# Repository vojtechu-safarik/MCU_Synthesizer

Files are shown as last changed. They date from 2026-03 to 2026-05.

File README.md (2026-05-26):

# Polyphonic Synthesizer for Teensy 4.1 

### Abstract
This project is an advanced realization of bachelor's project at Brno Univesity of Technology. 
It creates a digital synthesizer using a microcontroller development board, encompassing code development and a prototype build (including PCBs).
The C++ code has been made in VS Code using PlatformIO and it utilises Teensy Audio Library. 
The scripts that generate wavetables (as a header file) have been made using Python.
Those header files have been further edited in order to lower the amount of anti-aliasing using a MATLAB script. 

[**Video demonstration of the Synthesizer**](https://youtu.be/89R-V2SBuqk)

## Synthesis controls

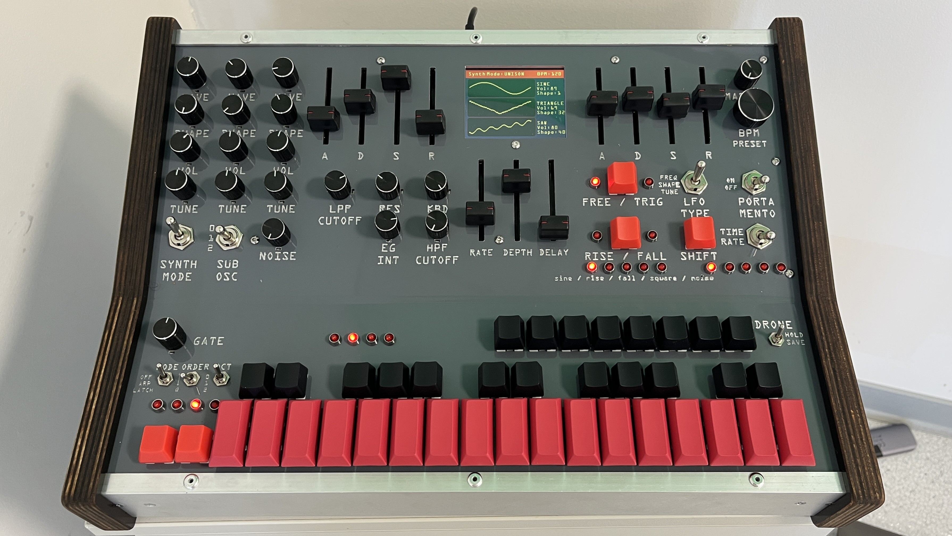
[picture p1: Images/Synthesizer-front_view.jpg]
Synthesizer - front view


### Oscillators
The synthesizer features both Poly and Unison voice allocation modes. Sound generation relies on wavetables categorized into 6 distinct families: Saw, Square (featuring Pulse Width Modulation), Triangle, Sine, Instrument, and Voice. Users can select the waveform type using the `Wave` control and seamlessly interpolate between variations using the `Shape` parameter. In Poly mode, each note gets its own independent audio chain, while Unison mode stacks three parallel oscillators per note for a thicker sound. Additionally, a sub-oscillator can be introduced, transposing the primary frequency one or two octaves down.

### Filters
The signal chain utilizes two main filters. The primary is a 24 dB/oct resonant Low-Pass Filter based on the Huovilainen New Moog mathematical model, which is capable of self-oscillation. This is followed in series by a 12 dB/oct High-Pass Filter based on the State Variable Filter model. The Low-Pass Filter also includes a dedicated Keyboard Tracking feature, allowing the cutoff frequency to scale dynamically with the pitch of the note played.

### Envelopes
Each voice is equipped with two dedicated ADSR (Attack, Decay, Sustain, Release) envelopes, allowing stages up to 3 seconds in length. One envelope shapes the final amplitude of the signal, while the other modulates the Low-Pass Filter's cutoff frequency. The filter envelope also features an `Intensity` control, enabling users to finely scale or invert the depth of the modulation.

### LFO
The Low-Frequency Oscillator can modulate the LPF Cutoff, Oscillator Shape, and Voice Pitch (Detune). It features four operational modes: `Free` (a single global LFO for all voices), `Retrig` (independent LFO per voice), and `Rise` or `Fall` (one-shot linear modulations triggered per note). Available waveforms include Sine, Saw Rise, Saw Fall, Square, and a randomized Noise sample. Users can adjust the modulation `Rate` (0.1–25 Hz), `Depth`, and a fade-in `Delay` of up to 3 seconds.

### Portamento
Available exclusively in Unison mode, Portamento introduces a smooth glide between overlapping notes. Its speed is synchronized to the global BPM and can be operated in two modes: `Time`, where the glide duration is a fixed note division regardless of the pitch distance, and `Rate`, where the glide duration scales with the interval, defined by the time it takes to travel one octave.

### Sequencer
A built-in step sequencer synchronizes to the global BPM and features two main performance modes. `Arp` mode functions as a traditional arpeggiator playing held notes in sequence, whereas `Latch` mode captures pressed keys into a buffer and plays them continuously without requiring the keys to be held. The sequence playback can be customized with order settings (Up, Down, As Played), octave duplications (+1 or +2 octaves), and an adjustable `Gate` parameter defining the note length (1–100%) per step. There's also an option to adjust the each individual step length via secret settings.

### Drone
This alternative ambient mode leverages 10 additional parallel oscillator chains utilizing simplified SVF filters, split into two alternating groups (A and B), alongside independent noise generators. Using the `Save` mode, users can capture the exact parameter settings of currently active voices and store them to one of 8 dedicated buttons. Switching to `Hold` mode allows users to endlessly play back these captured static drones concurrently with the standard synthesis engine.

## List of hardware components

* Teensy 4.1 Development board

* Audio Adaptor Board for Teensy (Rev D)

* 16-Channel Analog/Digital Multiplexer/Demultiplexer, CD74HC4067
  - used for various parameter configuration via potentiometers and toggle switches
  - 3 modules used in total 

  ### Mux 1 Channels:
  | Mux Channel | Parameter name | Connected Component |
  | :--- | :--- | :--- |
  | C0 | **Wave 1** | **Potentiometer** |
  | C1 | **Wave 2** | **Potentiometer** |
  | C2 | **Wave 3** | **Potentiometer** |
  | C3 | **Shape 1** | **Potentiometer** |
  | C4 | **Shape 2** | **Potentiometer** |
  | C5 | **Shape 3** | **Potentiometer** |
  | C6 | **Volume 1** | **Potentiometer** |
  | C7 | **Volume 2** | **Potentiometer** |
  | C8 | **Volume 3** | **Potentiometer** |
  | C9 | **Tune 1** | **Potentiometer** |
  | C10 | **Tune 2** | **Potentiometer** |
  | C11 | **Tune 3** | **Potentiometer** |
  | C12 | **Pink Noise** | **Potentiometer** |
  | C13 | **SynthMode - Poly** | **2-way Toggle Switch** |
  | C14 | **Sub-OSC - OFF** | **3-way Toggle Switch** |
  | C15 | **Sub-OSC - +2 octaves** | **3-way Toggle Switch** |

  ### Mux 2 Channels:
  | Mux Channel | Parameter name | Connected Component |
  | :--- | :--- | :--- |
  | C0 | **LPF Cutoff** | **Potentiometer** |
  | C1 | **LPF Resonance** | **Potentiometer** |
  | C2 | **Keyboard Tracking** | **Potentiometer** |
  | C3 | **Filter Envelope Intensity** | **Potentiometer** |
  | C4 | **HPF Cutoff** | **Potentiometer** |
  | C5 | **Filter Attack** | **Potentiometer** |
  | C6 | **Filter Decay** | **Potentiometer** |
  | C7 | **Filter Sustain** | **Potentiometer** |
  | C8 | **Filter Release** | **Potentiometer** |
  | C9 | **LFO Rate** | **Potentiometer** |
  | C10 | **LFO Depth** | **Potentiometer** |
  | C11 | **LFO Delay** | **Potentiometer** |
  | C12 | **Amplitude Attack** | **Potentiometer** |
  | C13 | **Amplitude Decay** | **Potentiometer** |
  | C14 | **Amplitude Sustain** | **Potentiometer** |
  | C15 | **Amplitude Release** | **Potentiometer** |

  ### Mux 3 Channels:
  | Mux Channel | Parameter name | Connected Component |
  | :--- | :--- | :--- |
  | C0 | **Master Volume** | **Potentiometer** |
  | C1 | **Sequencer Gate** | **Potentiometer** |
  | C2 | **LFO Type - Frequency** | **3-way Toggle Switch** |
  | C3 | **LFO Type - Tune** | **3-way Toggle Switch** |
  | C4 | **Portamento - ON** | **2-way Toggle Switch** |
  | C5 | **Portamento - Mode** | **2-way Toggle Switch** |
  | C6 | **Drone - mode** | **2-way Toggle Switch** |
  | C7 | **Sequencer Mode - OFF** | **3-way Toggle Switch** |
  | C8 | **Sequencer Mode - Latch** | **3-way Toggle Switch** |
  | C9 | **Sequencer Order - Up** | **3-way Toggle Switch** |
  | C10 | **Sequencer Order - Queue** | **3-way Toggle Switch** |
  | C11 | **Sequencer Octaves - 0** | **3-way Toggle Switch** |
  | C12 | **Sequencer Octaves - 2** | **3-way Toggle Switch** |

* 8-bit I/O Expander I2C-Bus, PCF8574T
  - used for LED signals for parameter state identification 
  - 2 modules used in total 

  ### I/O Expander 1 Pinout:
  | I/O Expander Pin | Parameter name |
  | :--- | :--- |
  | P0 | **LFO Mode #1** |
  | P1 | **LFO Mode #2** |
  | P2 | **LFO Mode #3** |
  | P3 | **LFO Mode #4** |
  | P4 | **LFO Wave #1** |
  | P5 | **LFO Wave #2** |
  | P6 | **LFO Wave #3** |
  | P7 | **LFO Wave #4** |

  ### I/O Expander 2 Pinout:
  | I/O Expander Pin | Parameter name |
  | :--- | :--- |
  | P0 | **Sequencer Rate #3** |
  | P1 | **Sequencer Rate #4** |
  | P2 | **LFO Wave #5** |
  | P3 | **Portamento Rate #1** |
  | P4 | **Portamento Rate #2** |
  | P5 | **Portamento Rate #3** |
  | P6 | **Portamento Rate #4** |
  | P7 | **Portamento Rate #5** |

* 3.2" 240x320 TFT display, ILI9341
  - SPI Display used for wavetable state reading

* Potentiometers
  - 20 Rotary B5K (WH148)
  - 11 Slider B10K (60mm)

* Rotary Encoder, KY-040
  - used for BPM configuration
  - button is used for preset selection

* Keyboard switches, MX linear Red
  - set up as a matrix to preserve pins

  Keyboard matrix configuration

* Toggle switches
- 3× KN3 2-way toggle switch
- 2× KN3 3-way toggle switch
- 1× MTS-102 2-way toggle switch
- 3× MTS-103 3-way toggle switch

* Basic electronic components
- Resistors
  - 1× 100 (for Display backlight)
  - 22× 1k (for LEDs)
  - 14× 10k (pull resistors)
- Capacitors
  - 5× Ceramic 100nF (for coupling)
- Diodes
  - 43× 1N4148 (for Keyboard switches)
- LEDs
  - 22× 3mm Red
- Terminal blocks
  - 45× 3-Pin 2.54mm
  - 6× 2-Pin 2.54mm

## Circuit & PCB schematics
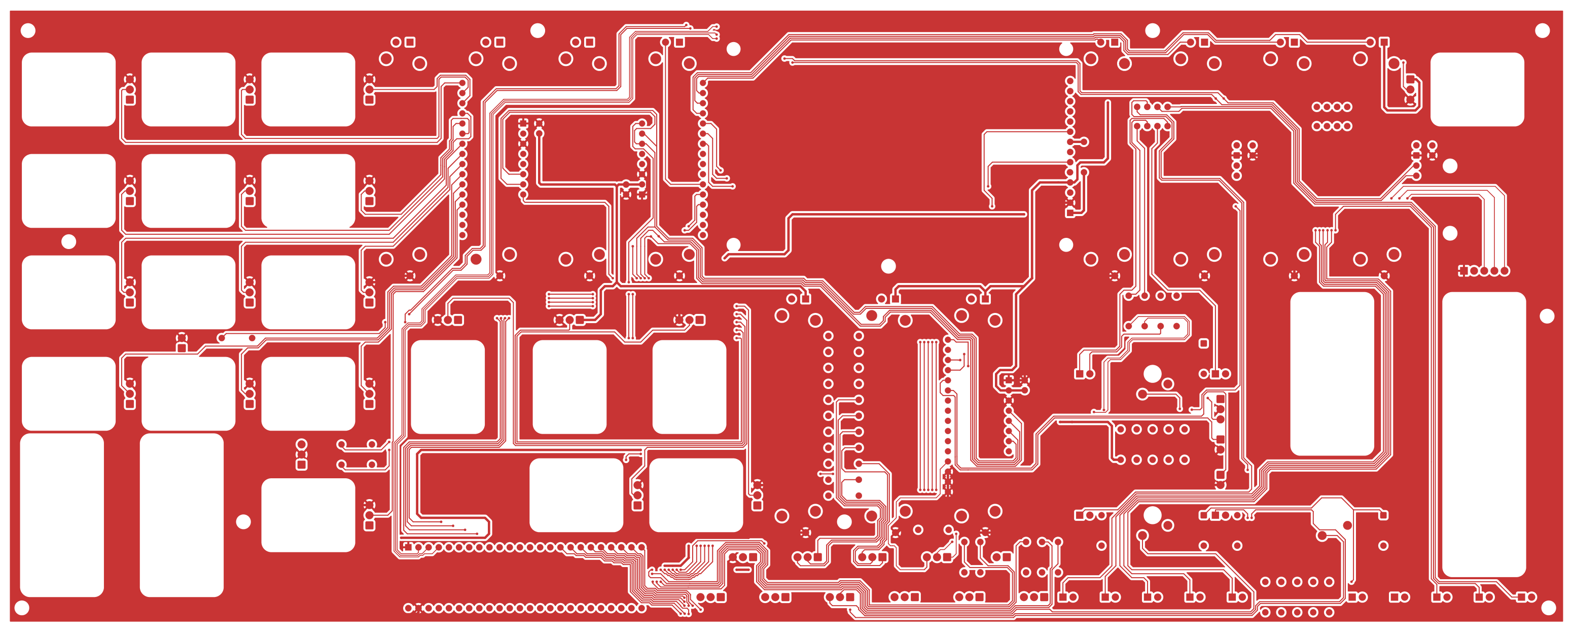
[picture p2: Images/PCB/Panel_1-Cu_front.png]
Main panel PCB - Copper Top

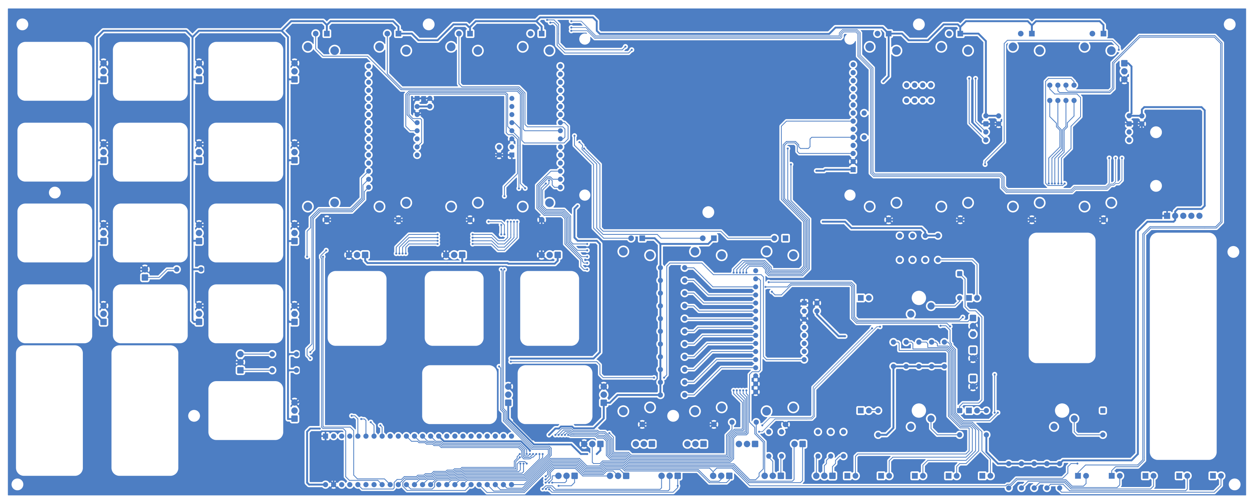
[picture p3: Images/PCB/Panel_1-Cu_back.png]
Main panel PCB - Copper Bottom

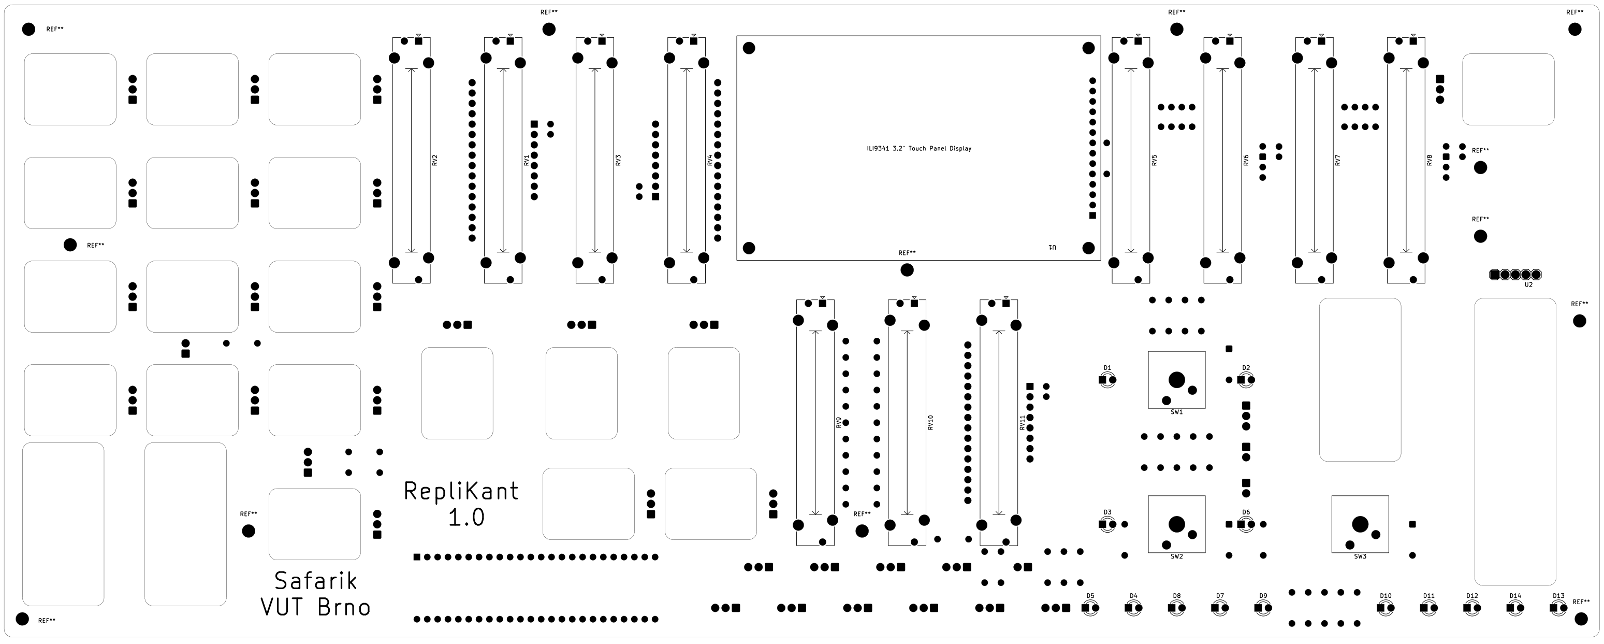
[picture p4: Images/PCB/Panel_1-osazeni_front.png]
Main panel PCB - Parts Top

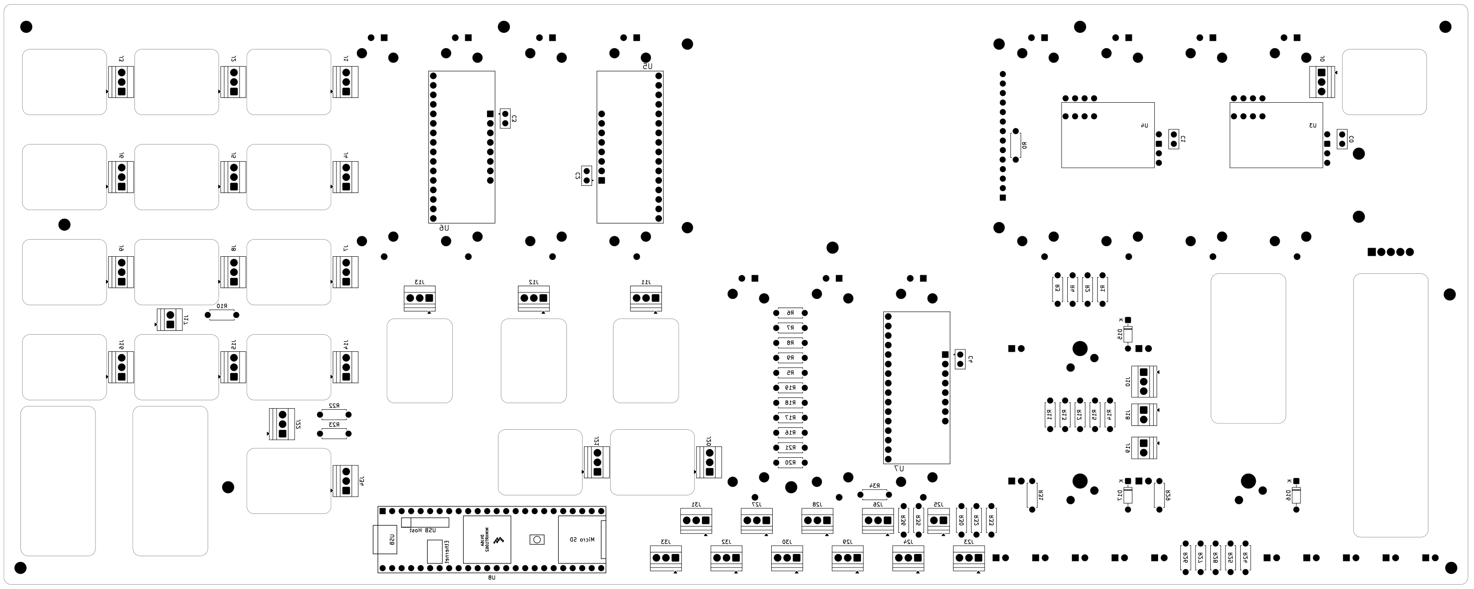
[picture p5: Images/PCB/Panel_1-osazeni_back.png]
Main panel PCB - Parts Bottom

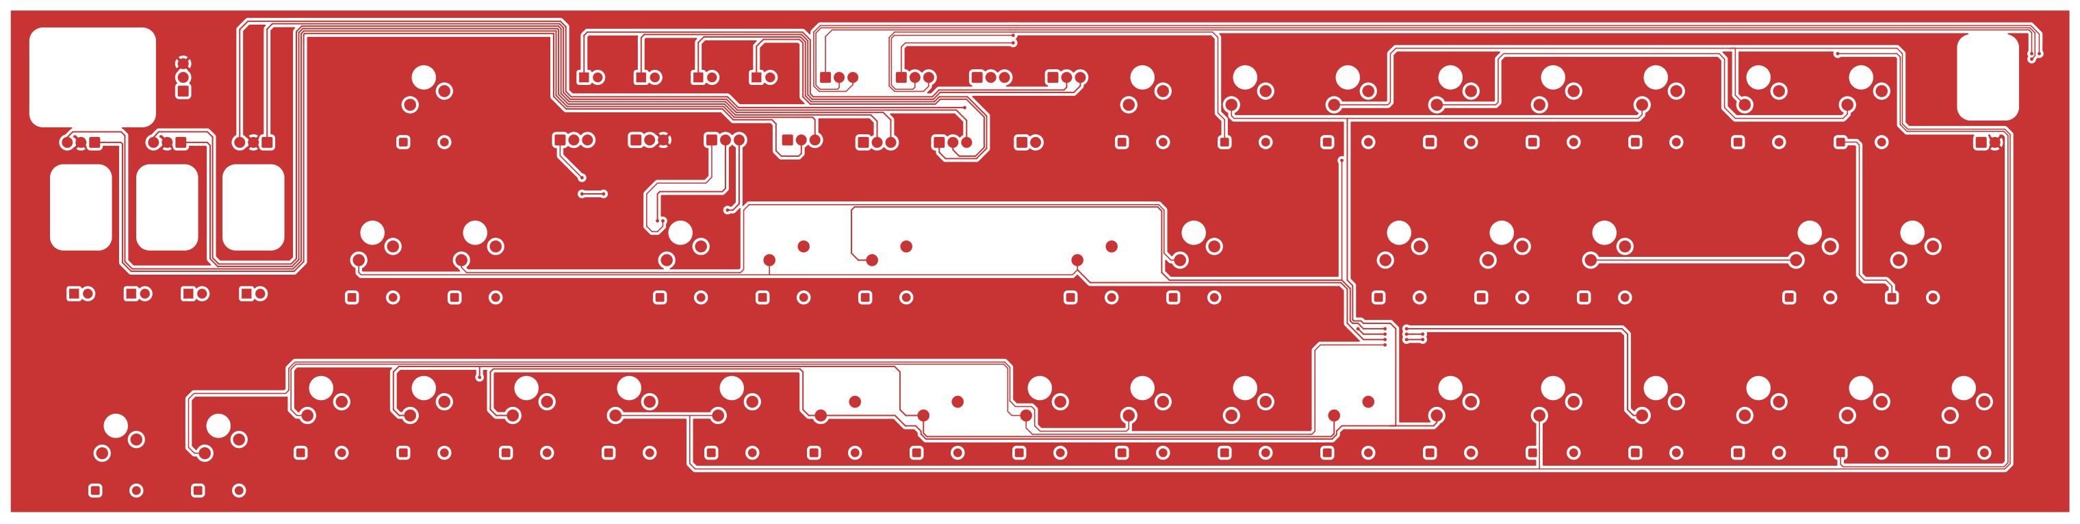
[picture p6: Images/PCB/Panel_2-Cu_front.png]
Keyboard panel PCB - Copper Top

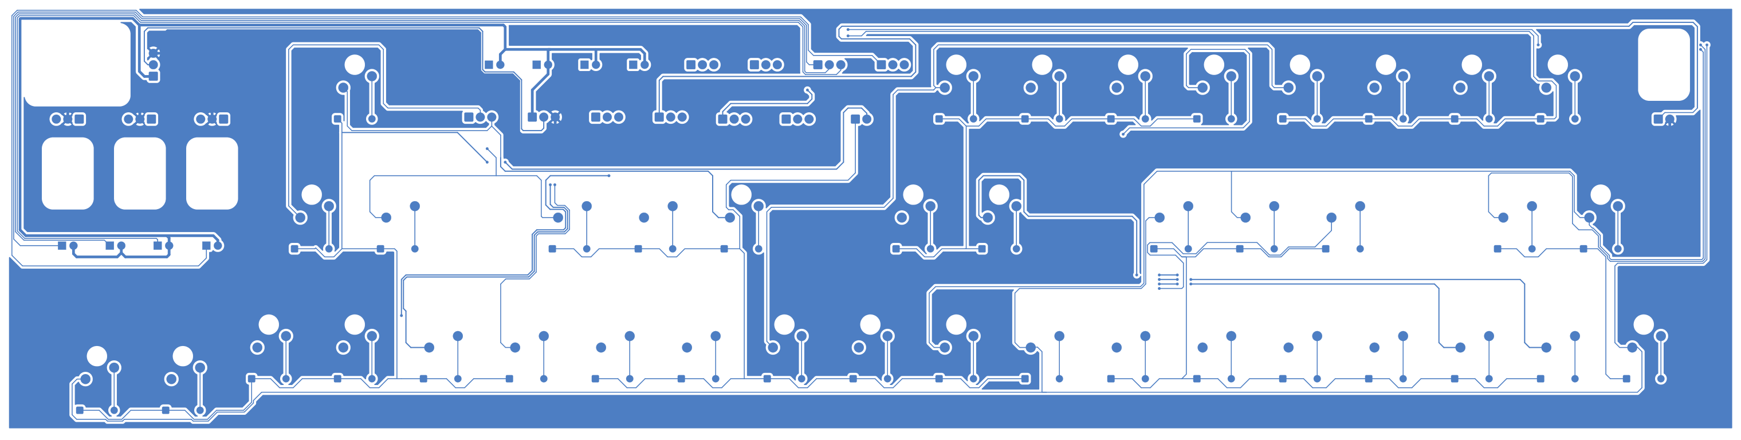
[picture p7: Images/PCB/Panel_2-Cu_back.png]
Keyboard panel PCB - Copper Bottom

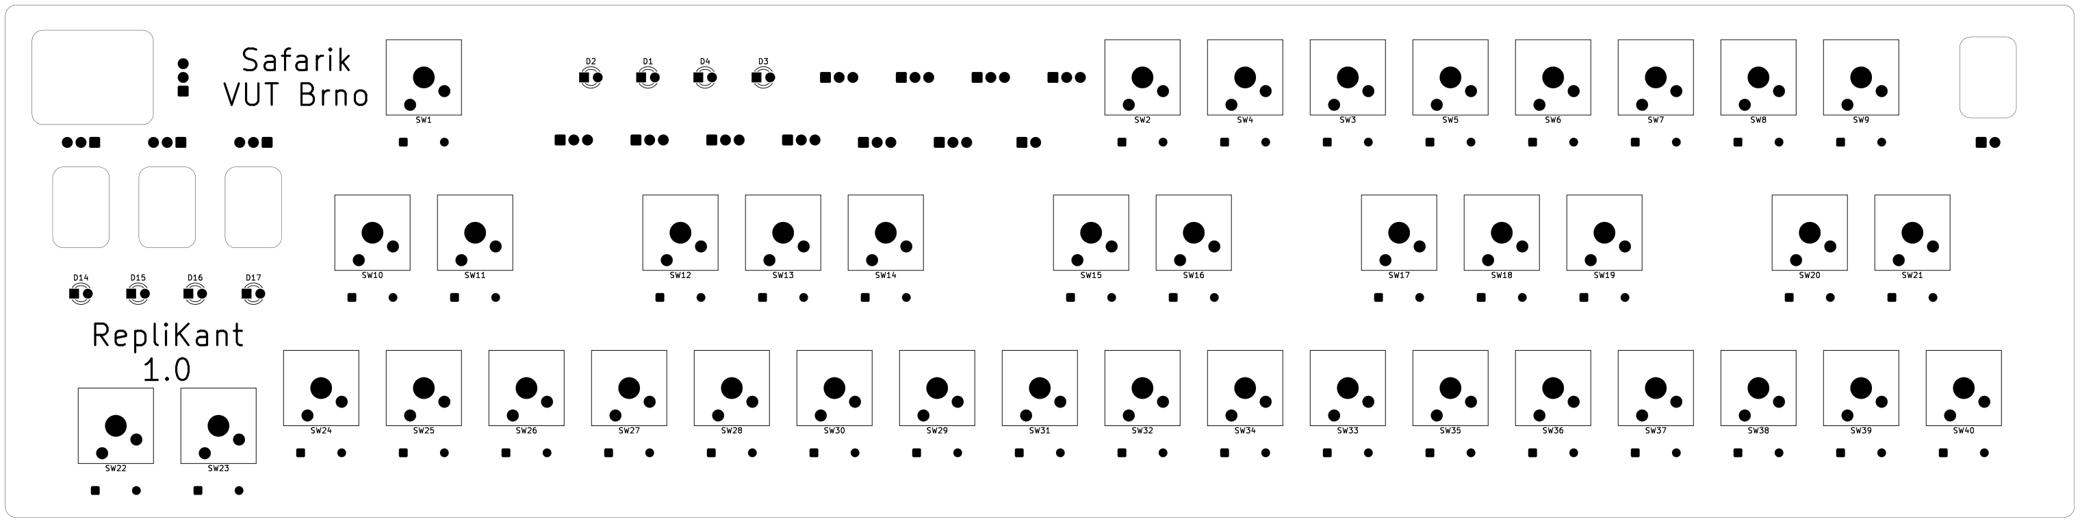
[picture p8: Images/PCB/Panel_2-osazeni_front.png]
Keyboard panel PCB - Parts Top

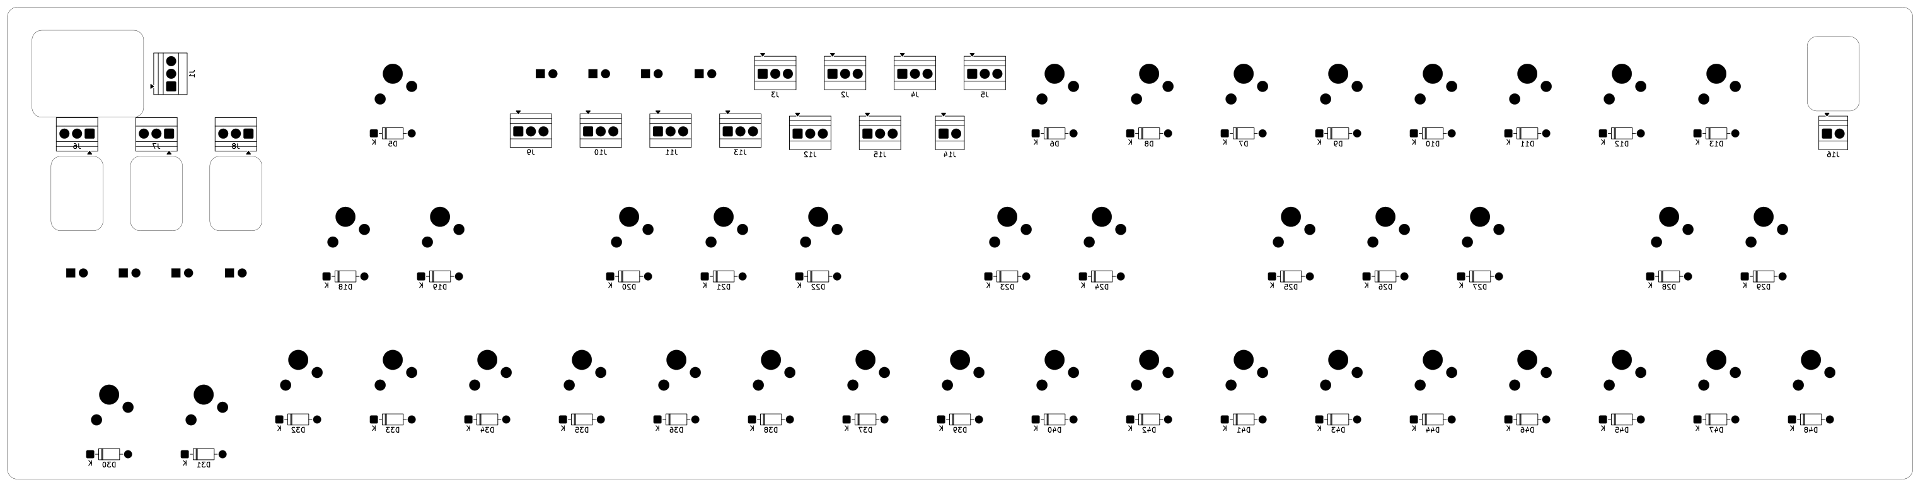
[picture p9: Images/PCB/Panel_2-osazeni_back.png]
Keyboard panel PCB - Parts Bottom


Circuit & PCB schematics have been made in KiCad 9.0 and the project is available [here.](./Design/KiCad)

## Pinout Configuration

| Teensy Pin | Pin name | Connected Components |
| :--- | :--- | :--- |
| 0 | **SW** | **Rotary Encoder** |
| 1 | **DT** | **Rotary Encoder** |
| 2 | **CLK** | **Rotary Encoder** |
| 3 | **S0** | **Mux #1, #2 and #3** |
| 4 | **S1** | **Mux #1, #2 and #3** |
| 5 | **S2** | **Mux #1, #2 and #3** |
| 6 | **S3** | **Mux #1, #2 and #3** |
| 7 | **DIN** | **Audioshield** |
| 8 | **DOUT** | **Audioshield** |
| 9 | **D/C** | **Display** |
| 10 | **CS** | **Display** |
| 11 | **SDI (MOSI)** | **Display** |
| 12 | **SDO (MISO)** | **Display** |
| 13 | **SCK** | **Display** |
| 14 | **Signal #1** | **LED #1 (Sequencer Rate #1)** |
| 15 | **Signal #2** | **LED #2 (Octave #4)** |
| 16 | **Signal #3** | **LED #3 (Octave #3)** |
| 17 | **Signal #4** | **LED #4 (Octave #2)** |
| 18 | **SDA** | **Audioshield** |
| 19 | **SCL** | **Audioshield** |
| 20 | **LRCLK** | **Audioshield** |
| 21 | **BCLK** | **Audioshield** |
| 22 | **Signal #5** | **LED #5 (Octave #1)** |
| 23 | **MCLK** | **Audioshield** |
| 24 | **Row #1** | **Keyboard** |
| 25 | **Row #2** | **Keyboard** |
| 26 | **Row #3** | **Keyboard** |
| 27 | **Row #4** | **Keyboard** |
| 28 | **Row #5** | **Keyboard** |
| 29 | **Row #6** | **Keyboard** |
| 30 | **Row #7** | **Keyboard** |
| 31 | **Row #8** | **Keyboard** |
| 32 | **Row #9** | **Keyboard** |
| 33 | **Column #1** | **Keyboard** |
| 34 | **Column #2** | **Keyboard** |
| 35 | **Column #3** | **Keyboard** |
| 36 | **Column #4** | **Keyboard** |
| 37 | **Column #5** | **Keyboard** |
| 38 | **Signal #6** | **LED #6 (Sequencer Rate #2)** |
| 39 | **Sig (A15)** | **Mux #1** |
| 40 | **Sig (A16)** | **Mux #2** |
| 41 | **Sig (A17)** | **Mux #3** |

### Images

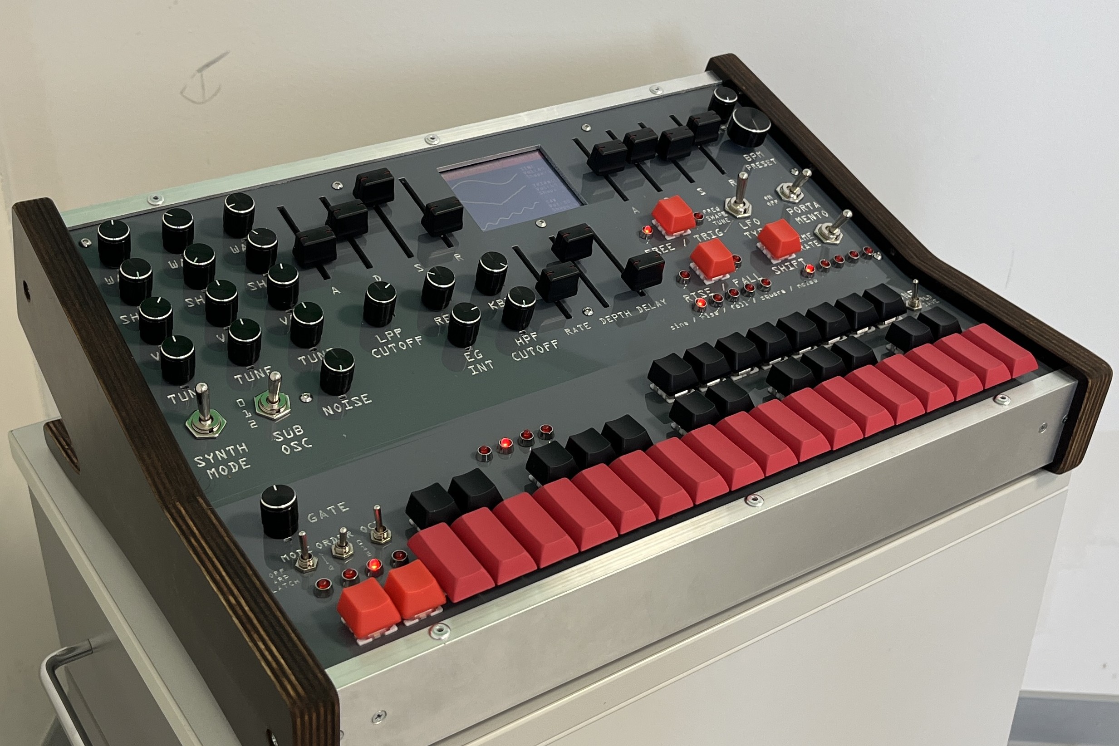
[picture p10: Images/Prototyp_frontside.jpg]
Look from the front

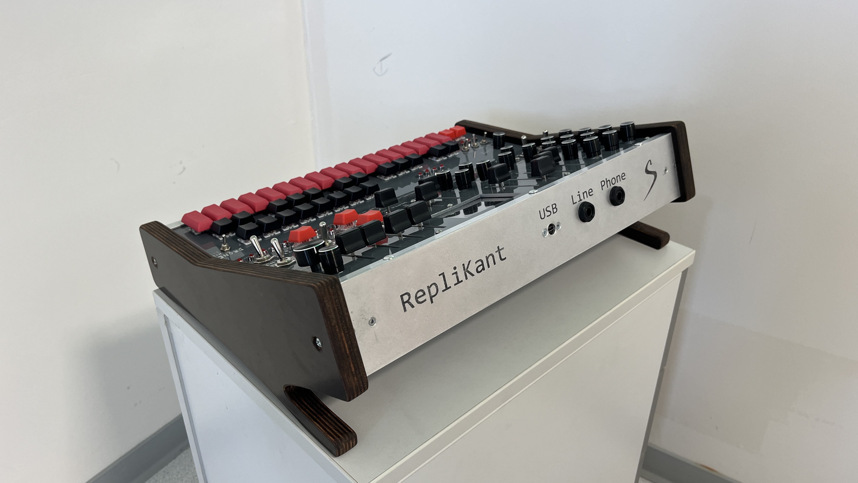
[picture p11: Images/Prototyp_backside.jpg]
Look from the back

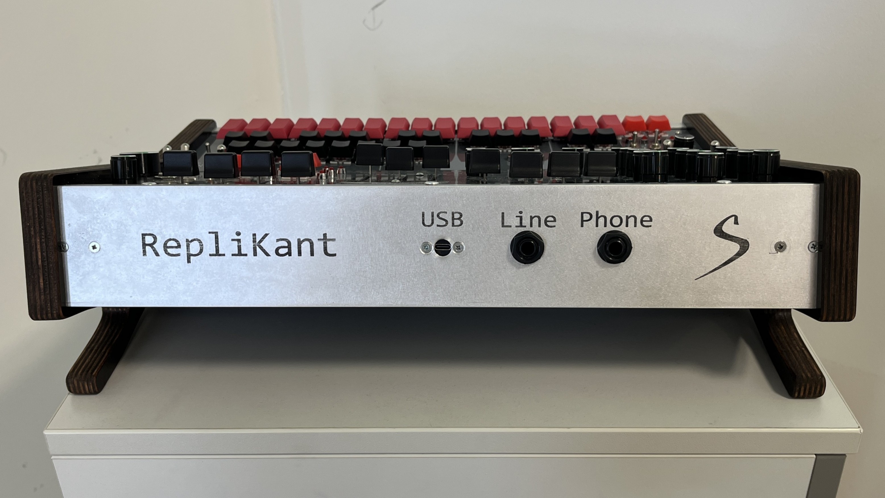
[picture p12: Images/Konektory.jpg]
Connectors


### 3D Model

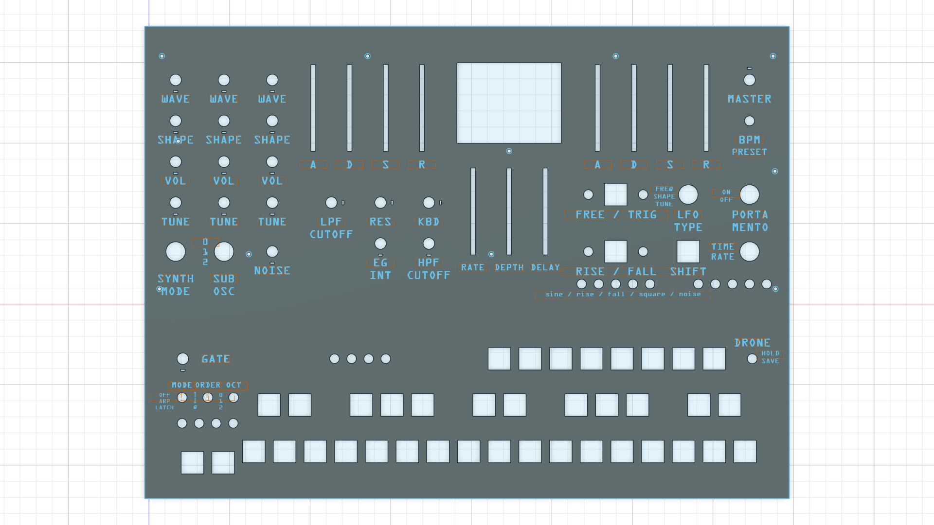
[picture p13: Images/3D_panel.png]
3D Panel


The 3D model has been made for laser engraving of the control panel. 

### Possible improvements

* The Line Out connector doesn't work now, and I don't know why, but I suppose it's not of mechanical nature.
* The GND is pretty noisy as of now, especially when powering via USB.
* Preset function isn't developed yet, but will be once I return to this project later.

## References

* Teensy 4.1 information: [link PJRC.com](https://www.pjrc.com/store/teensy41.html)
* Audio Adaptor Board for Teensy information: [link PJRC.com](https://www.pjrc.com/store/teensy3_audio.html)
* Incredible source of information and amazing YouTube content: [link notesandvolts.com](https://www.notesandvolts.com)
* I hereby acknowledge use of free-license AI tool for coding: [link gemini.google.com](https://gemini.google.com)

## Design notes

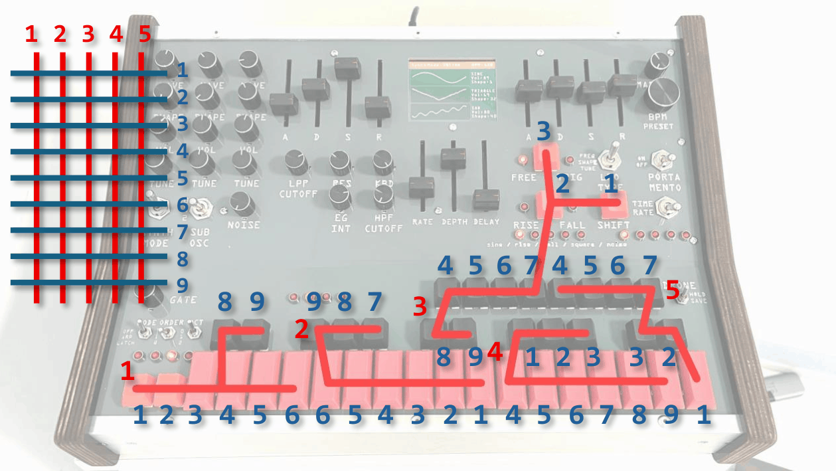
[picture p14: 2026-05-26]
Images/Keyboard_matrix_configuration-1.png

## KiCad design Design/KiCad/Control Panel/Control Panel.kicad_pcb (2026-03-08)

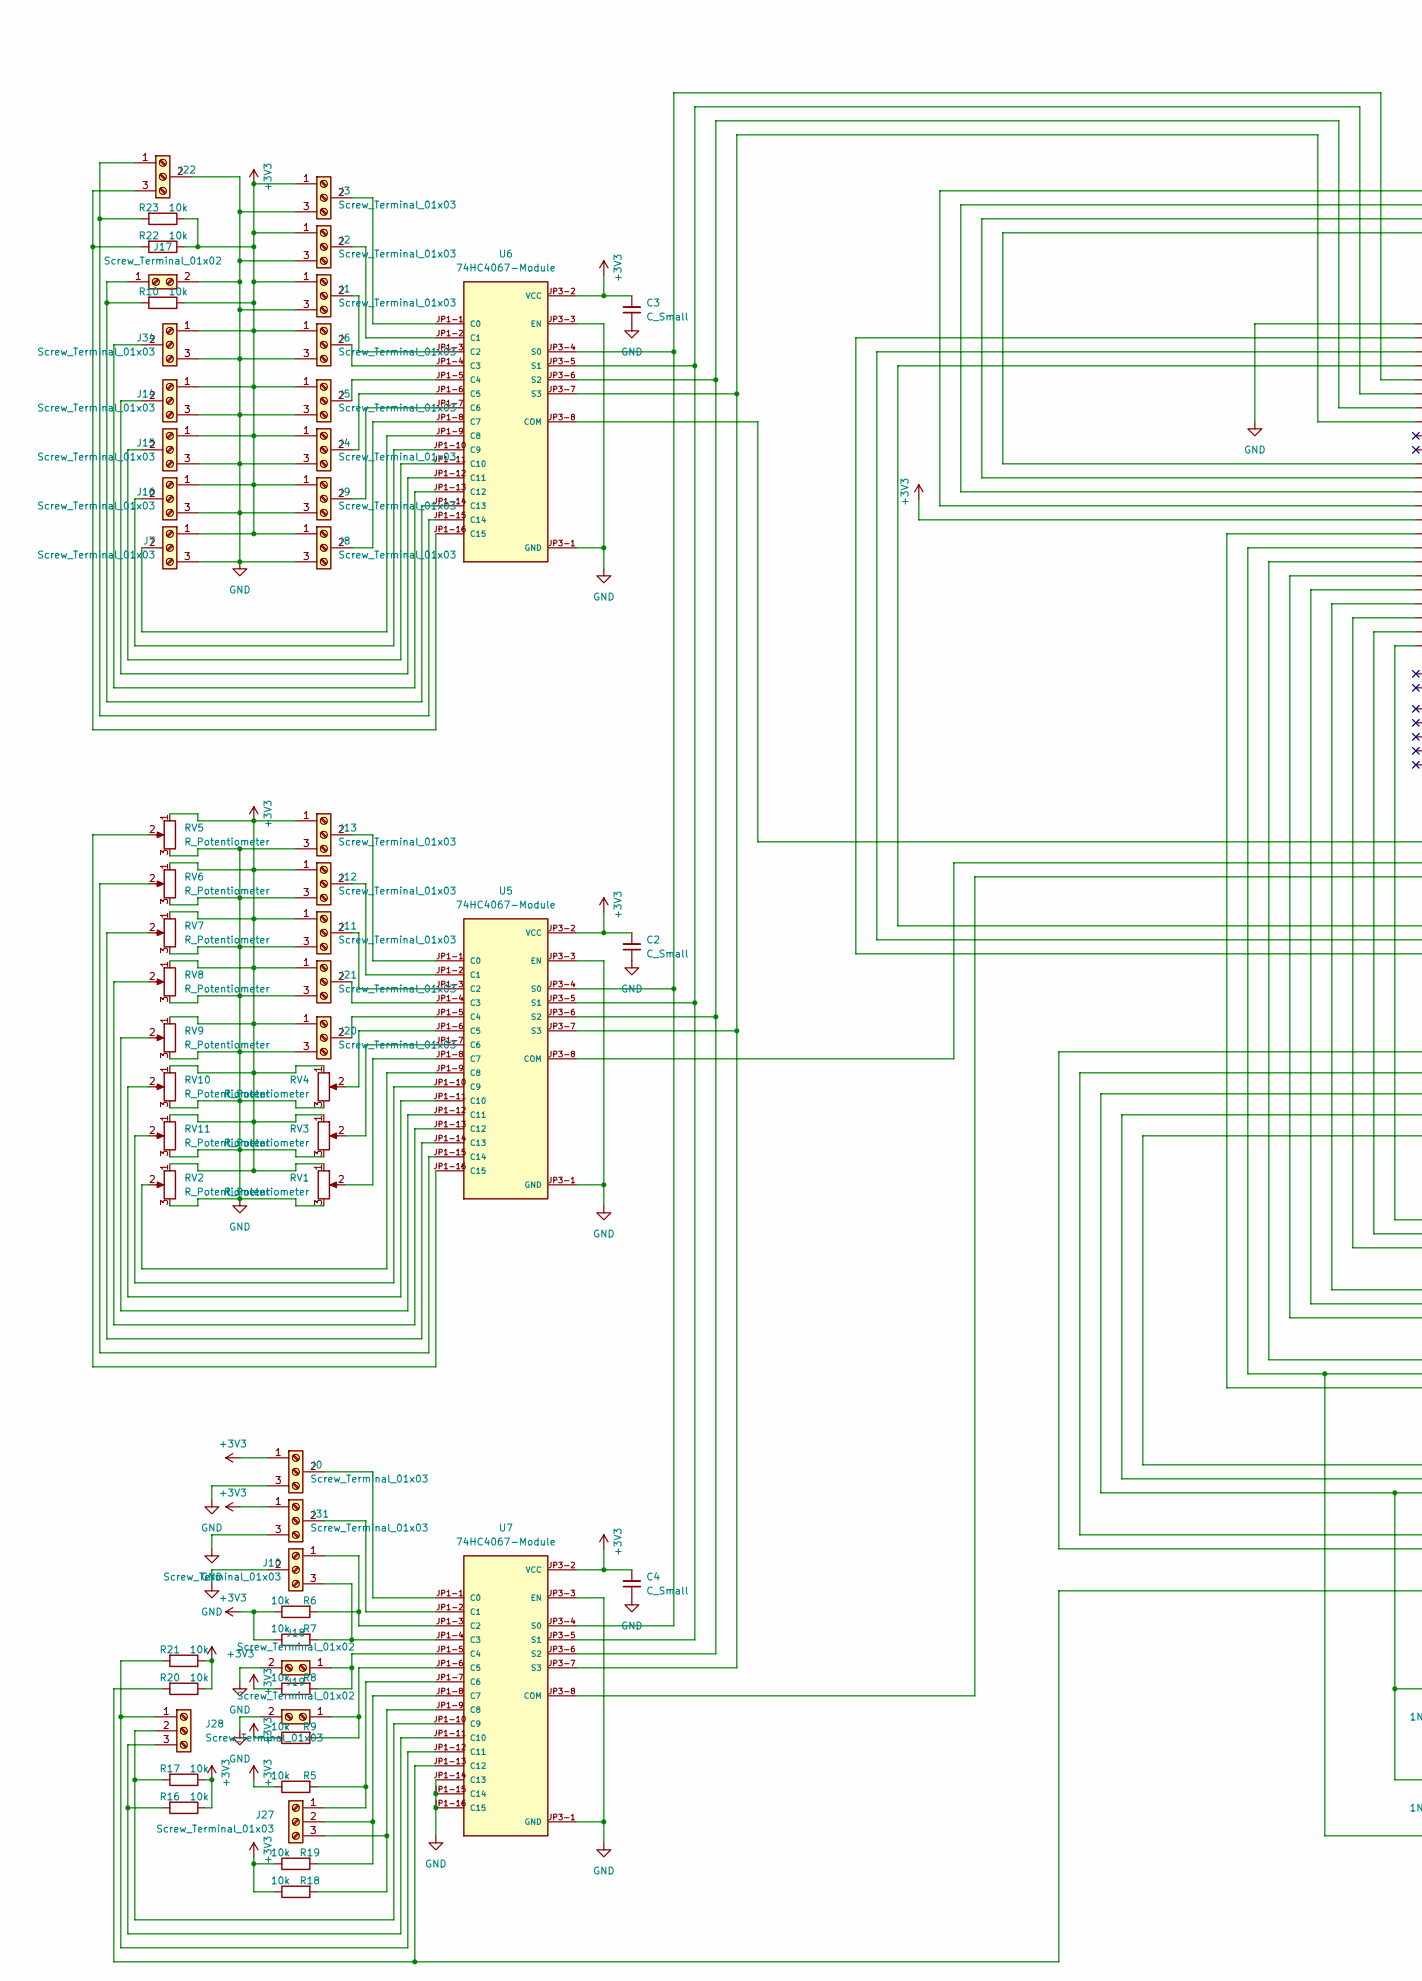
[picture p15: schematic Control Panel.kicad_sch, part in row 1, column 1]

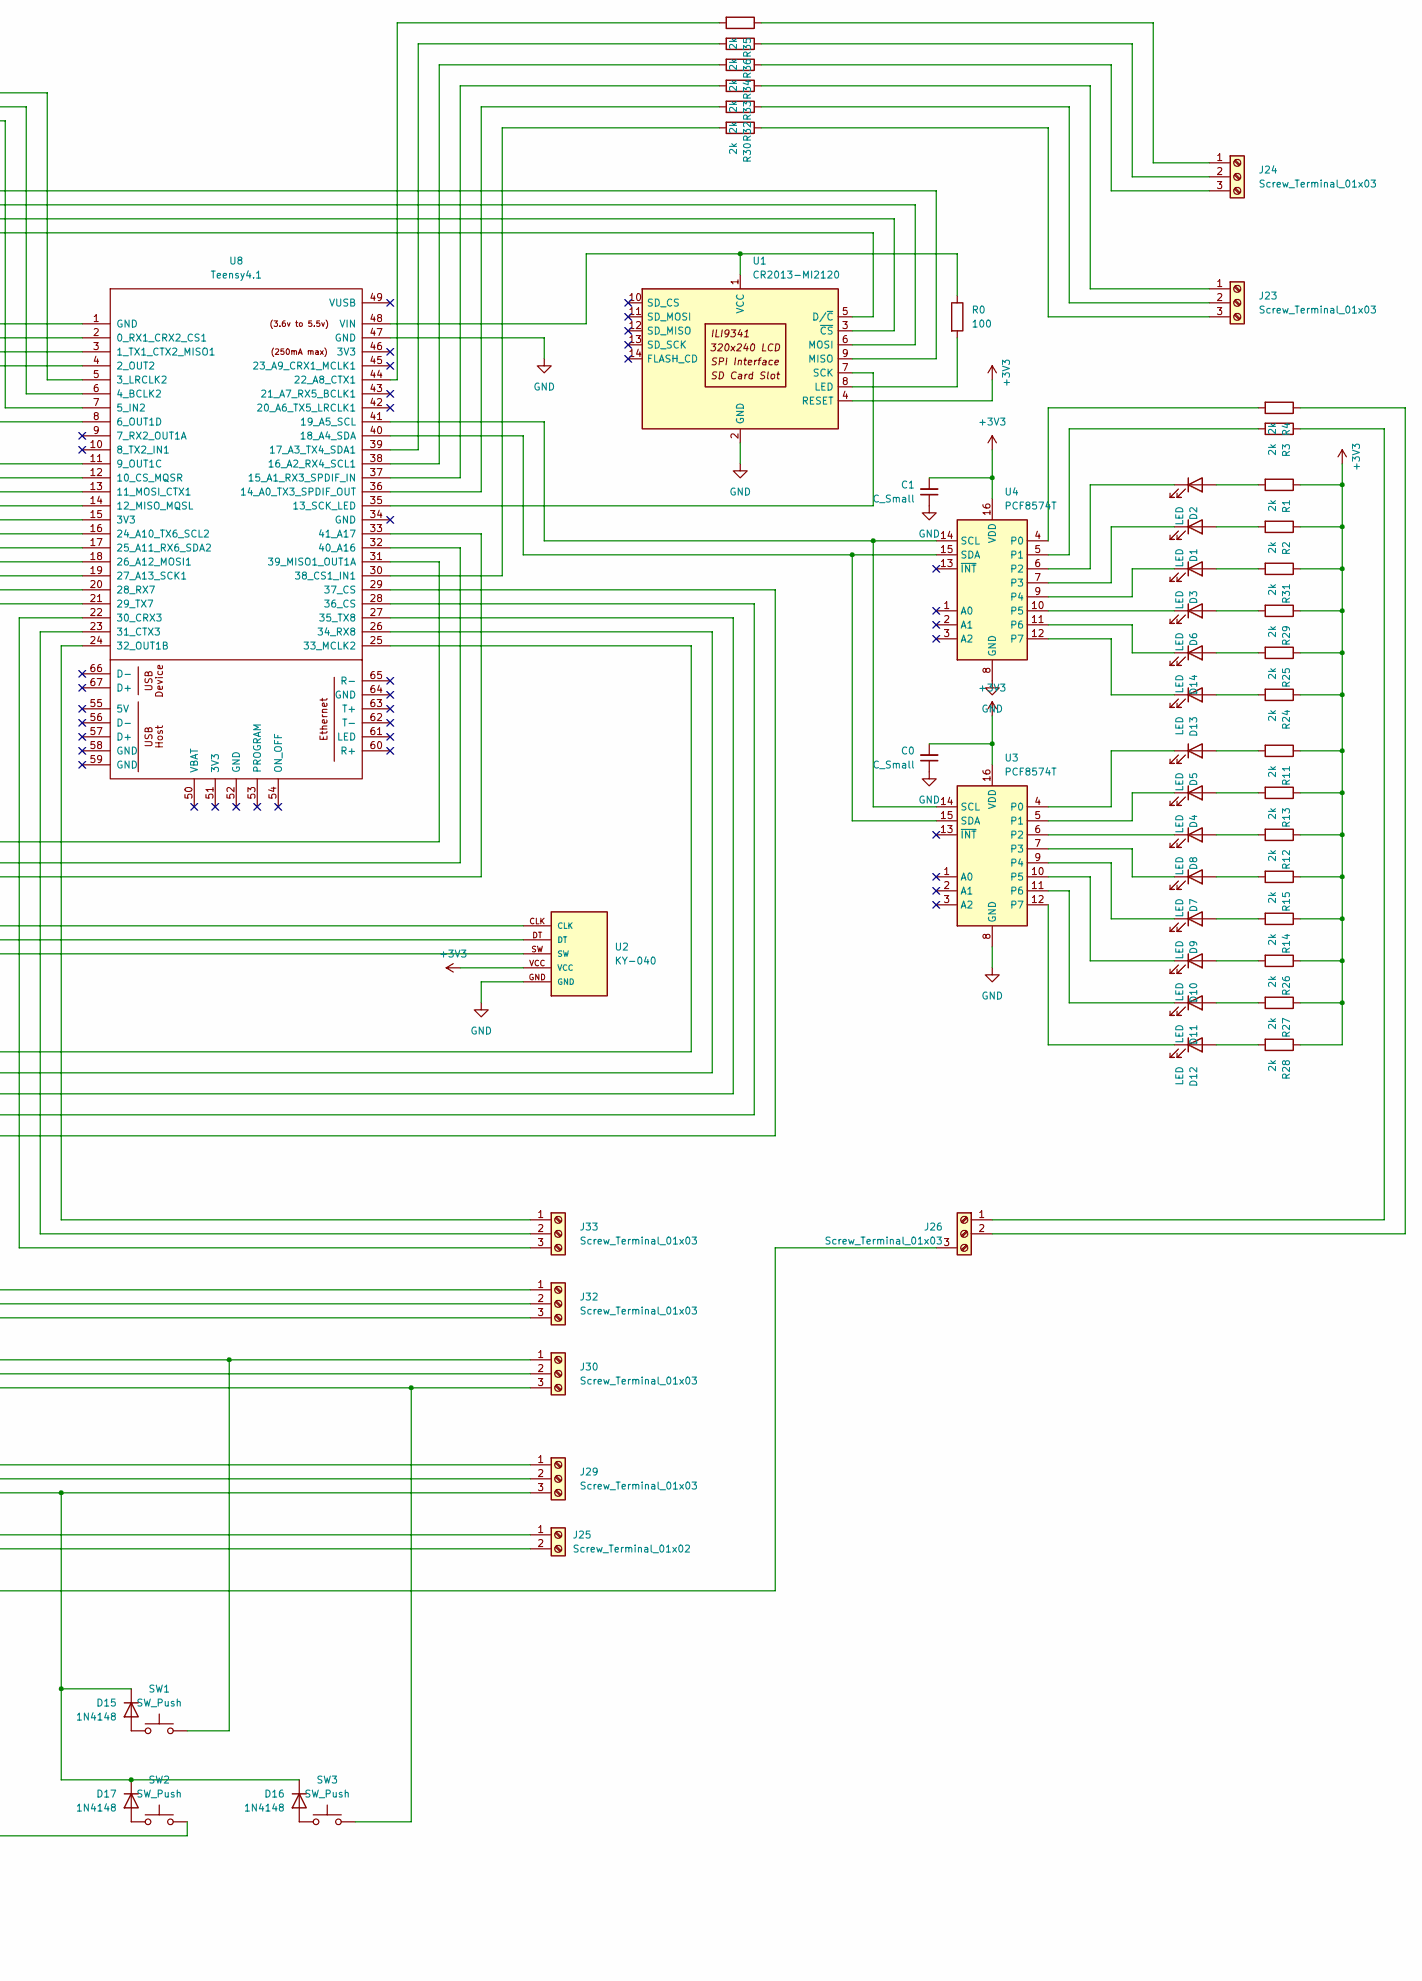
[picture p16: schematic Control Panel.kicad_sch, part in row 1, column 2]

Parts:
C0, C1, C2, C3, C4: C_Small; C_Disc_D5.0mm_W2.5mm_P2.50mm
D1, D2, D3, D4, D5, D6, D7, D8, D9, D10, D11, D12, D13, D14: LED; LED_D3.0mm_Clear
D15, D16, D17: 1N4148; D_DO-35_SOD27_P7.62mm_Horizontal
J0, J1, J2, J3, J4, J5, J6, J7, J8, J9, J10, J11, J12, J13, J14, J15, J16, J20, J21, J22, J23, J24, J26, J27, J28, J29, J30, J31, J32, J33, J34: Screw_Terminal_01x03; TerminalBlock_Xinya_XY308-2.54-3P_1x03_P2.54mm_Horizontal
J17, J18, J19, J25: Screw_Terminal_01x02; TerminalBlock_Xinya_XY308-2.54-2P_1x02_P2.54mm_Horizontal
R0: 100; R_Axial_DIN0207_L6.3mm_D2.5mm_P7.62mm_Horizontal
R1, R2, R3, R4, R11, R12, R13, R14, R15, R24, R25, R26, R27, R28, R29, R30, R31, R32, R33, R34, R35, R36: 2k; R_Axial_DIN0207_L6.3mm_D2.5mm_P7.62mm_Horizontal
R5, R6, R7, R8, R9, R10, R16, R17, R18, R19, R20, R21, R22, R23: 10k; R_Axial_DIN0207_L6.3mm_D2.5mm_P7.62mm_Horizontal
RV1, RV2, RV3, RV4, RV5, RV6, RV7, RV8, RV9, RV10, RV11: R_Potentiometer; Potentiometer_Bourns_PTA4543_Single_Slide
SW1, SW2, SW3: SW_Push; SW_Cherry_MX_1.00u_Plate
U1: CR2013-MI2120; ILI9341_3p2_320x240
U2: KY-040; KY-040-PORT
U3, U4: PCF8574T; PCF8574T_Custom
U5, U6, U7: 74HC4067-Module; MODULE-74HC4067; PARTREV v11
U8: Teensy4.1; Teensy41

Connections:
+3V3: C0.2, C1.2, C2.2, C3.2, C4.2, J0.1, J1.1, J2.1, J3.1, J4.1, J5.1, J6.1, J7.1, J8.1, J9.1, J11.1, J12.1, J13.1, J14.1, J15.1, J16.1, J20.1, J21.1, J31.1, J34.1, R1.1, R2.1, R5.1, R6.1, R7.1, R8.1, R9.1, R10.1, R11.1, R12.1, R13.1, R14.1, R15.1, R16.1, R17.1, R18.1, R19.1, R20.1, R21.1, R22.1, R23.1, R24.1, R25.1, R26.1, R27.1, R28.1, R29.1, R31.1, RV1.1, RV2.1, RV3.1, RV4.1, RV5.1, RV6.1, RV7.1, RV8.1, RV9.1, RV10.1, RV11.1, U1.4 (RESET), U2.VCC, U3.16 (VDD), U4.16 (VDD), U5.JP3-2 (VCC), U6.JP3-2 (VCC), U7.JP3-2 (VCC), U8.15 (3V3)
GND: C0.1, C1.1, C2.1, C3.1, C4.1, J0.3, J1.3, J2.3, J3.3, J4.3, J5.3, J6.3, J7.3, J8.3, J9.3, J10.2, J11.3, J12.3, J13.3, J14.3, J15.3, J16.3, J17.2, J18.2, J19.2, J20.3, J21.3, J22.2, J31.3, J34.3, RV1.3, RV2.3, RV3.3, RV4.3, RV5.3, RV6.3, RV7.3, RV8.3, RV9.3, RV10.3, RV11.3, U1.2 (GND), U2.GND, U3.8 (GND), U4.8 (GND), U5.JP3-1 (GND), U5.JP3-3 (EN), U6.JP3-1 (GND), U6.JP3-3 (EN), U7.JP1-14 (C13), U7.JP1-15 (C14), U7.JP1-16 (C15), U7.JP3-1 (GND), U7.JP3-3 (EN), U8.1 (GND), U8.47 (GND)
unnamed: D1.2 (A), R2.2
unnamed: D1.1 (K), U4.7 (P3)
unnamed: D2.2 (A), R1.2
unnamed: D2.1 (K), U4.6 (P2)
unnamed: D3.2 (A), R31.2
unnamed: D3.1 (K), U4.9 (P4)
unnamed: D4.2 (A), R13.2
unnamed: D4.1 (K), U3.5 (P1)
unnamed: D5.2 (A), R11.2
unnamed: D5.1 (K), U3.4 (P0)
unnamed: D6.2 (A), R29.2
unnamed: D6.1 (K), U4.10 (P5)
unnamed: D7.2 (A), R15.2
unnamed: D7.1 (K), U3.7 (P3)
unnamed: D8.2 (A), R12.2
unnamed: D8.1 (K), U3.6 (P2)
unnamed: D9.2 (A), R14.2
unnamed: D9.1 (K), U3.9 (P4)
unnamed: D10.2 (A), R26.2
unnamed: D10.1 (K), U3.10 (P5)
unnamed: D11.2 (A), R27.2
unnamed: D11.1 (K), U3.11 (P6)
unnamed: D12.2 (A), R28.2
unnamed: D12.1 (K), U3.12 (P7)
unnamed: D13.2 (A), R24.2
unnamed: D13.1 (K), U4.12 (P7)
unnamed: D14.2 (A), R25.2
unnamed: D14.1 (K), U4.11 (P6)
unnamed: D15.2 (A), SW1.2
unnamed: D15.1 (K), D16.1 (K), D17.1 (K), J29.3, U8.27 (35_TX8)
unnamed: D16.2 (A), SW3.2
unnamed: D17.2 (A), SW2.2
unnamed: J0.2, U7.JP1-1 (C0)
unnamed: J1.2, U6.JP1-3 (C2)
unnamed: J2.2, U6.JP1-2 (C1)
unnamed: J3.2, U6.JP1-1 (C0)
unnamed: J4.2, U6.JP1-6 (C5)
unnamed: J5.2, U6.JP1-5 (C4)
unnamed: J6.2, U6.JP1-4 (C3)
unnamed: J7.2, U6.JP1-9 (C8)
unnamed: J8.2, U6.JP1-8 (C7)
unnamed: J9.2, U6.JP1-7 (C6)
unnamed: J10.1, R6.2, U7.JP1-3 (C2)
unnamed: J10.3, R7.2, U7.JP1-4 (C3)
unnamed: J11.2, U5.JP1-3 (C2)
unnamed: J12.2, U5.JP1-2 (C1)
unnamed: J13.2, U5.JP1-1 (C0)
unnamed: J14.2, U6.JP1-12 (C11)
unnamed: J15.2, U6.JP1-11 (C10)
unnamed: J16.2, U6.JP1-10 (C9)
unnamed: J17.1, R10.2, U6.JP1-14 (C13)
unnamed: J18.1, R8.2, U7.JP1-5 (C4)
unnamed: J19.1, R9.2, U7.JP1-6 (C5)
unnamed: J20.2, U5.JP1-5 (C4)
unnamed: J21.2, U5.JP1-4 (C3)
unnamed: J22.1, R23.2, U6.JP1-15 (C14)
unnamed: J22.3, R22.2, U6.JP1-16 (C15)
unnamed: J23.1, R33.1
unnamed: J23.2, R32.1
unnamed: J23.3, R30.1
unnamed: J24.1, R35.1
unnamed: J24.2, R36.1
unnamed: J24.3, R34.1
unnamed: J25.1, U8.26 (34_RX8)
unnamed: J25.2, U8.25 (33_MCLK2)
unnamed: J26.1, R3.1
unnamed: J26.2, R4.1
unnamed: J26.3, R20.2, U7.JP1-13 (C12)
unnamed: J27.1, R5.2, U7.JP1-7 (C6)
unnamed: J27.2, R19.2, U7.JP1-8 (C7)
unnamed: J27.3, R18.2, U7.JP1-9 (C8)
unnamed: J28.1, R21.2, U7.JP1-12 (C11)
unnamed: J28.2, R17.2, U7.JP1-10 (C9)
unnamed: J28.3, R16.2, U7.JP1-11 (C10)
unnamed: J29.1, U8.29 (37_CS)
unnamed: J29.2, U8.28 (36_CS)
unnamed: J30.1, SW1.1, U8.18 (26_A12_MOSI1)
unnamed: J30.2, SW2.1, U8.17 (25_A11_RX6_SDA2)
unnamed: J30.3, SW3.1, U8.16 (24_A10_TX6_SCL2)
unnamed: J31.2, U7.JP1-2 (C1)
unnamed: J32.1, U8.21 (29_TX7)
unnamed: J32.2, U8.20 (28_RX7)
unnamed: J32.3, U8.19 (27_A13_SCK1)
unnamed: J33.1, U8.24 (32_OUT1B)
unnamed: J33.2, U8.23 (31_CTX3)
unnamed: J33.3, U8.22 (30_CRX3)
unnamed: J34.2, U6.JP1-13 (C12)
unnamed: U1.5 (D/~C), U8.11 (9_OUT1C)
unnamed: R0.2, U1.8 (LED)
unnamed: U1.9 (MISO), U8.14 (12_MISO_MQSL)
unnamed: U1.6 (MOSI), U8.13 (11_MOSI_CTX1)
unnamed: U1.7 (SCK), U8.35 (13_SCK_LED)
unnamed: R0.1, U1.1 (VCC), U8.48 (VIN)
unnamed: U1.3 (~CS), U8.12 (10_CS_MQSR)
unnamed: U3.14 (SCL), U4.14 (SCL), U8.41 (19_A5_SCL)
unnamed: U3.15 (SDA), U4.15 (SDA), U8.40 (18_A4_SDA)
unnamed: R4.2, U4.4 (P0)
unnamed: R3.2, U4.5 (P1)
unnamed: RV4.2, U5.JP1-6 (C5)
unnamed: RV3.2, U5.JP1-7 (C6)
unnamed: RV1.2, U5.JP1-8 (C7)
unnamed: RV2.2, U5.JP1-9 (C8)
unnamed: RV11.2, U5.JP1-10 (C9)
unnamed: RV10.2, U5.JP1-11 (C10)
unnamed: RV9.2, U5.JP1-12 (C11)
unnamed: RV8.2, U5.JP1-13 (C12)
unnamed: RV7.2, U5.JP1-14 (C13)
unnamed: RV6.2, U5.JP1-15 (C14)
unnamed: RV5.2, U5.JP1-16 (C15)
unnamed: U5.JP3-8 (COM), U8.32 (40_A16)
unnamed: U5.JP3-4 (S0), U6.JP3-4 (S0), U7.JP3-4 (S0), U8.5 (3_LRCLK2)
unnamed: U5.JP3-5 (S1), U6.JP3-5 (S1), U7.JP3-5 (S1), U8.6 (4_BCLK2)
unnamed: U5.JP3-6 (S2), U6.JP3-6 (S2), U7.JP3-6 (S2), U8.7 (5_IN2)
unnamed: U5.JP3-7 (S3), U6.JP3-7 (S3), U7.JP3-7 (S3), U8.8 (6_OUT1D)
unnamed: U6.JP3-8 (COM), U8.31 (39_MISO1_OUT1A)
unnamed: U7.JP3-8 (COM), U8.33 (41_A17)
unnamed: U2.SW, U8.2 (0_RX1_CRX2_CS1)
unnamed: U2.DT, U8.3 (1_TX1_CTX2_MISO1)
unnamed: U2.CLK, U8.4 (2_OUT2)
unnamed: R32.2, U8.36 (14_A0_TX3_SPDIF_OUT)
unnamed: R33.2, U8.37 (15_A1_RX3_SPDIF_IN)
unnamed: R34.2, U8.38 (16_A2_RX4_SCL1)
unnamed: R36.2, U8.39 (17_A3_TX4_SDA1)
unnamed: R35.2, U8.44 (22_A8_CTX1)
unnamed: R30.2, U8.30 (38_CS1_IN1)

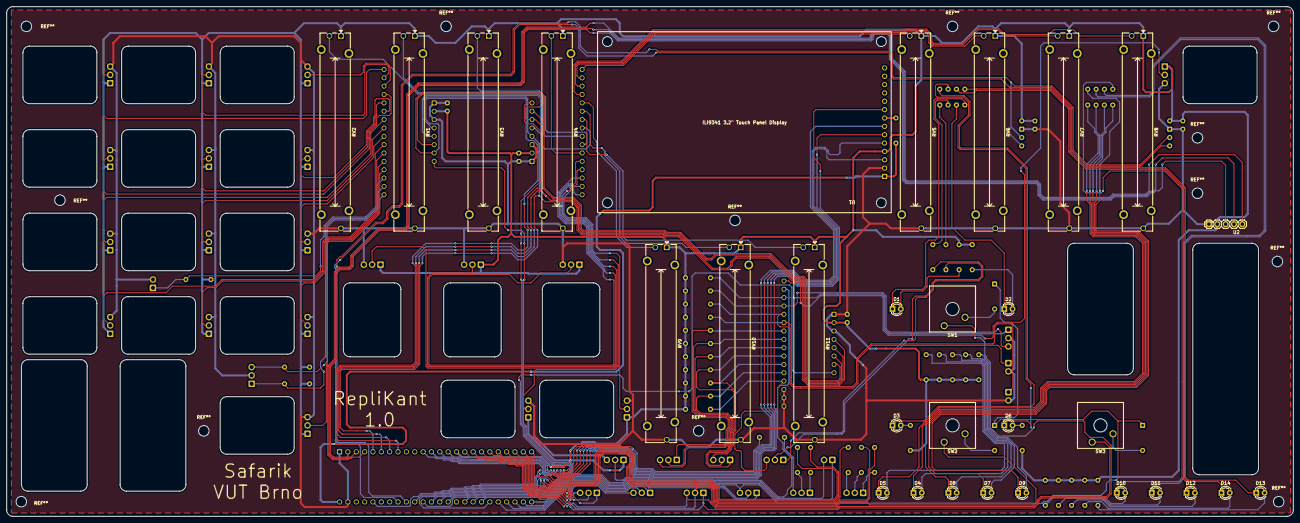
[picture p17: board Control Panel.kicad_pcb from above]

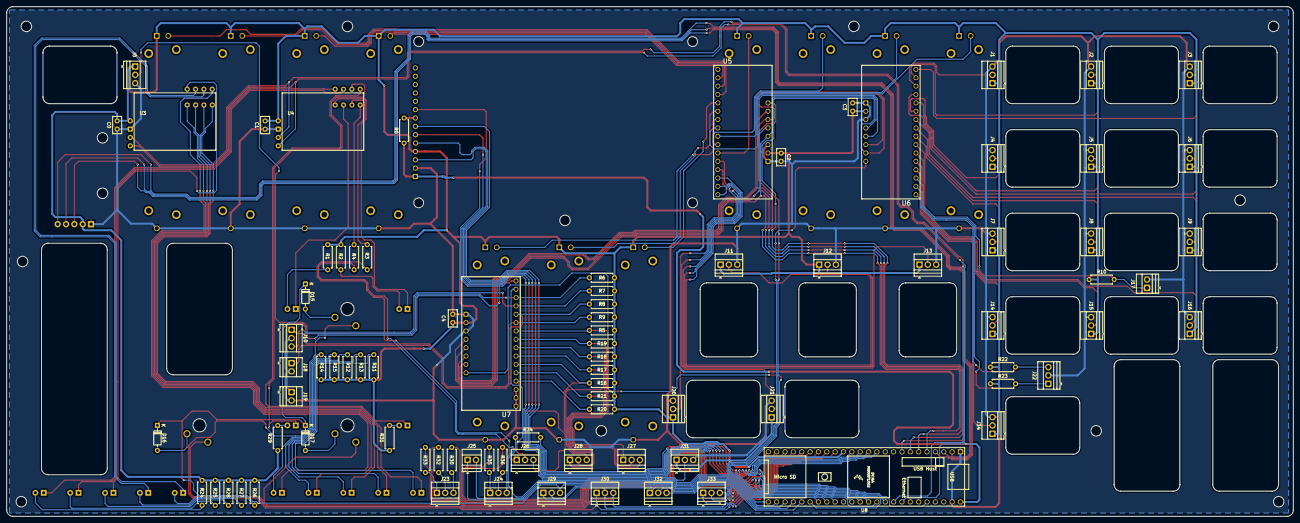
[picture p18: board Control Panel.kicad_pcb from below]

Board: 2 copper layers, 391.3 x 155.0 mm, 116 parts (86 on the bottom side), 127 nets.

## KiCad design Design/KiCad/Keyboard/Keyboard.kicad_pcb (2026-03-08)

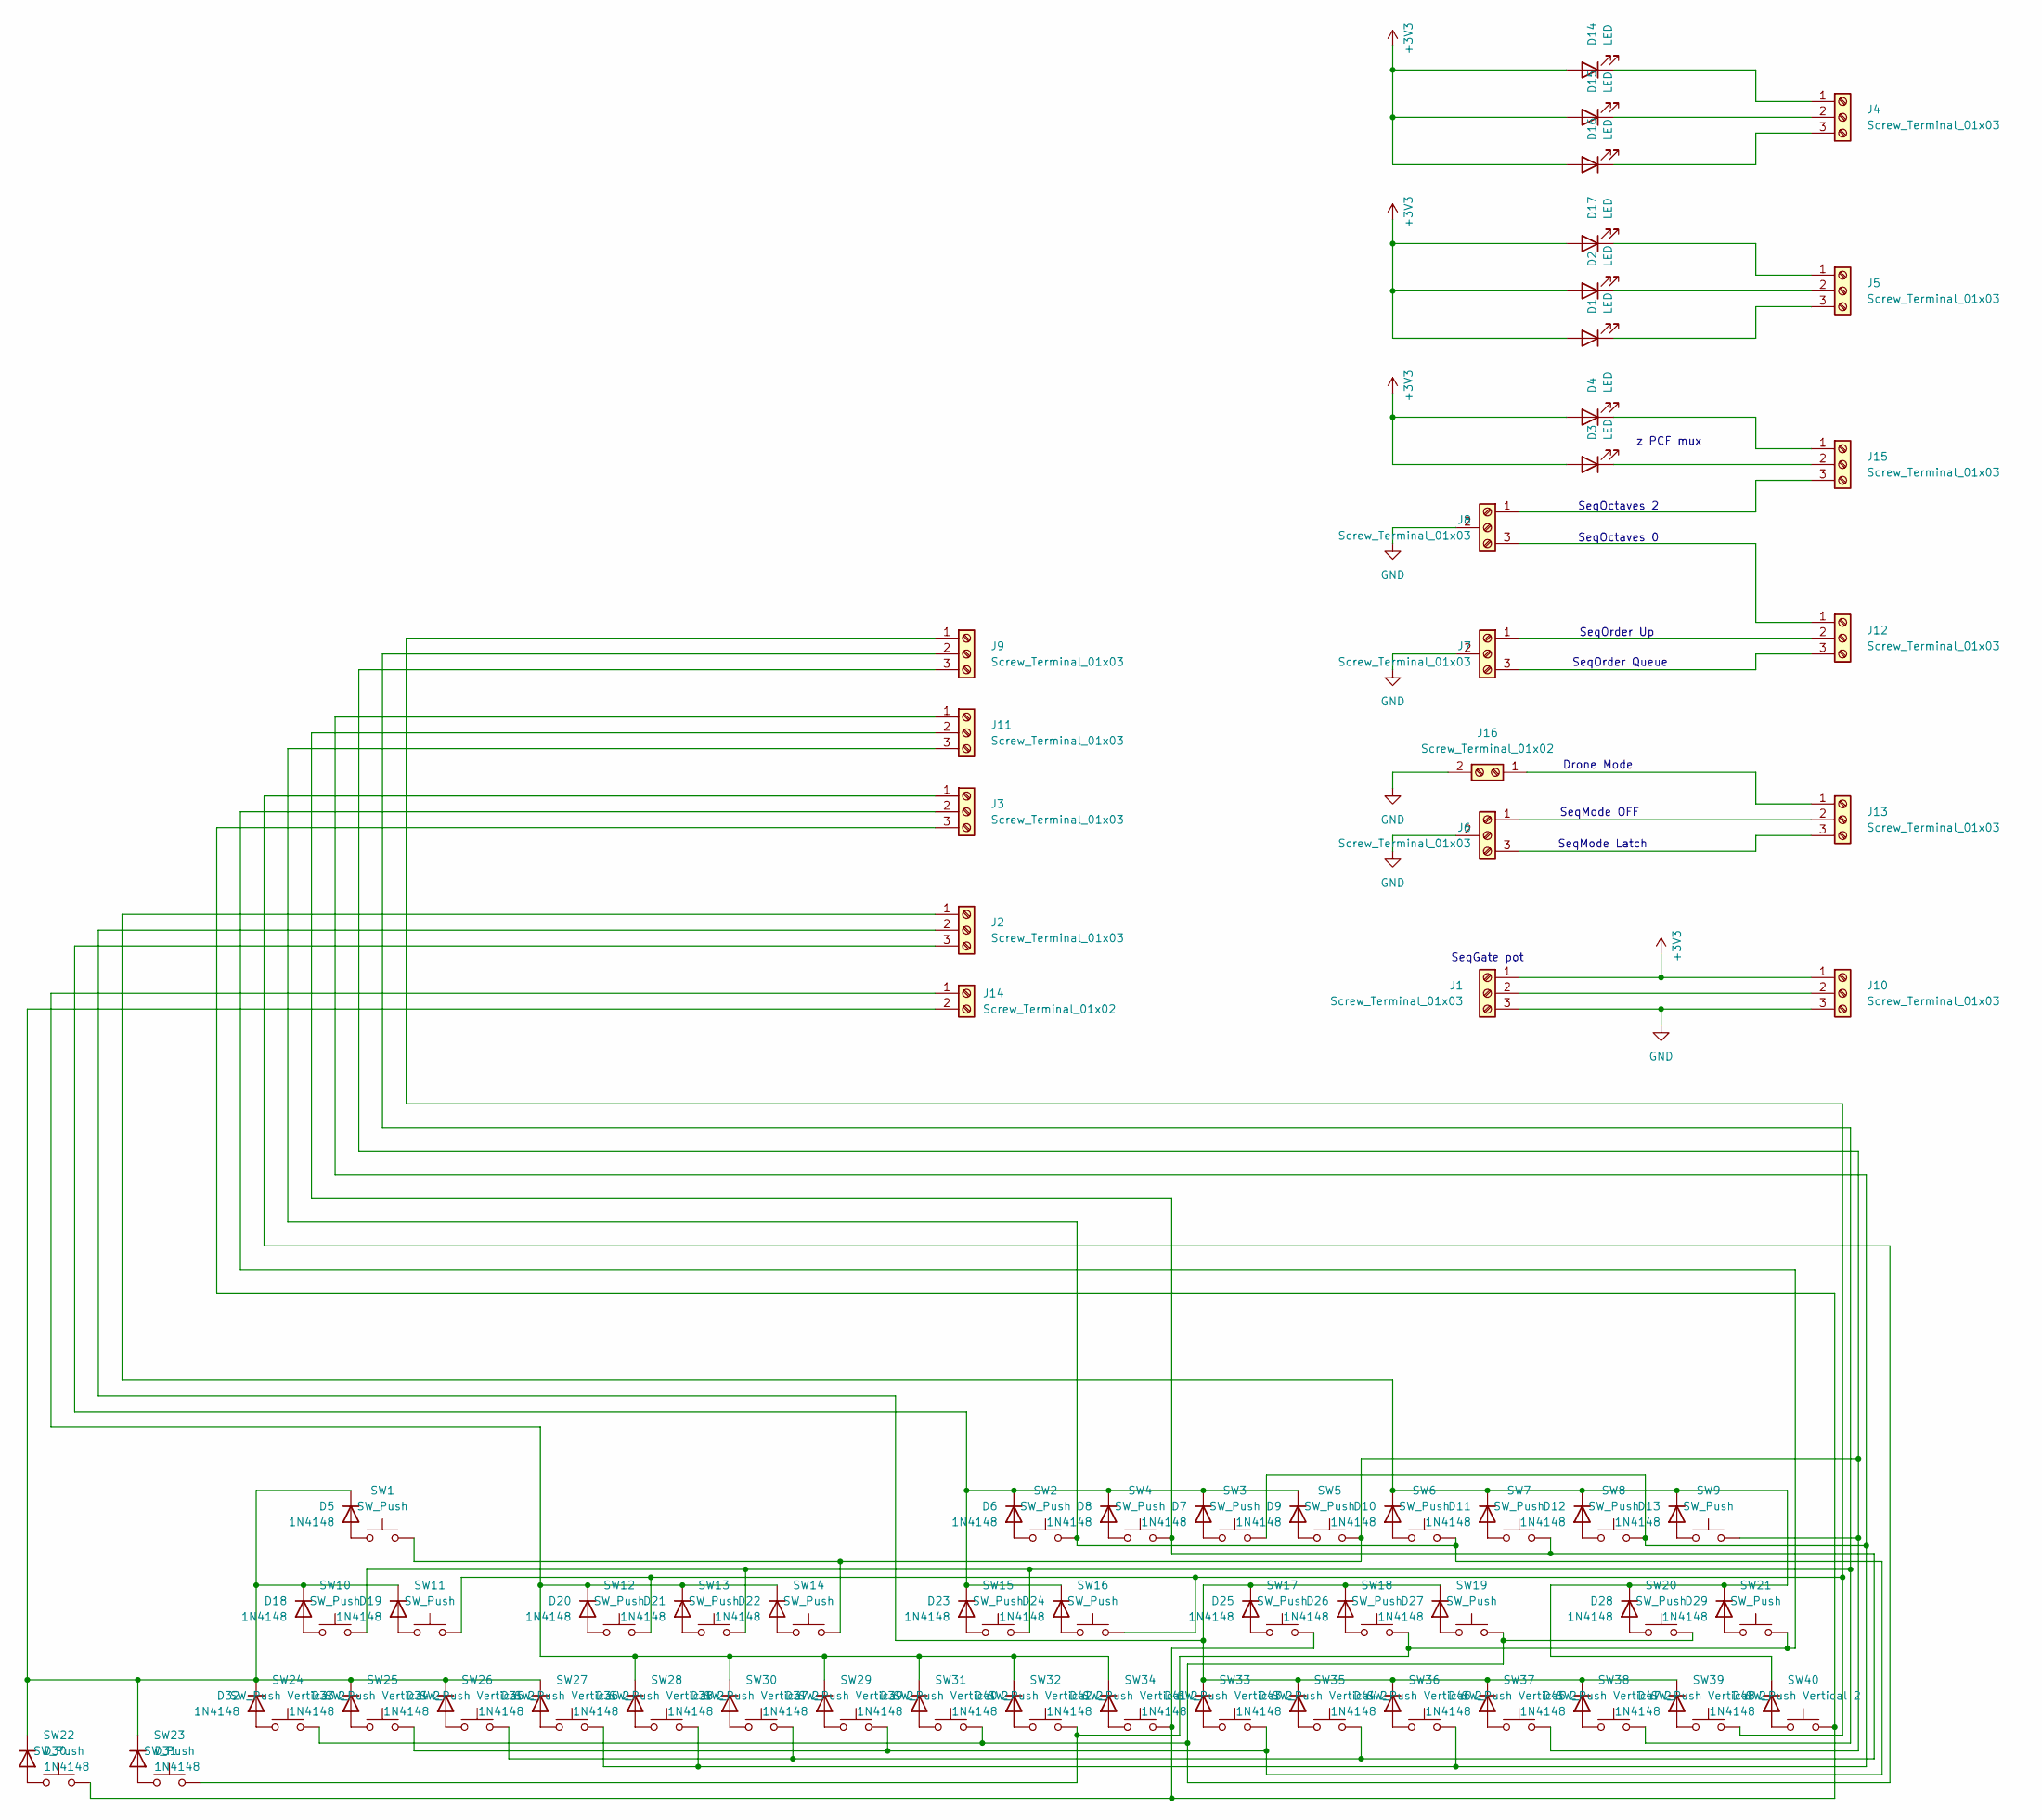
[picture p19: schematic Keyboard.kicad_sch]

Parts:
D1, D2, D3, D4, D14, D15, D16, D17: LED; LED_D3.0mm_Clear
D5, D6, D7, D8, D9, D10, D11, D12, D13, D18, D19, D20, D21, D22, D23, D24, D25, D26, D27, D28, D29, D30, D31, D32, D33, D34, D35, D36, D37, D38, D39, D40, D41, D42, D43, D44, D45, D46, D47, D48: 1N4148; D_DO-35_SOD27_P7.62mm_Horizontal
J1, J2, J3, J4, J5, J6, J7, J8, J9, J10, J11, J12, J13, J15: Screw_Terminal_01x03; TerminalBlock_Xinya_XY308-2.54-3P_1x03_P2.54mm_Horizontal
J14, J16: Screw_Terminal_01x02; TerminalBlock_Xinya_XY308-2.54-2P_1x02_P2.54mm_Horizontal
SW1, SW2, SW3, SW4, SW5, SW6, SW7, SW8, SW9, SW10, SW11, SW12, SW13, SW14, SW15, SW16, SW17, SW18, SW19, SW20, SW21, SW22, SW23: SW_Push; SW_Cherry_MX_1.00u_Plate
SW24, SW25, SW26, SW27, SW28, SW29, SW30, SW31, SW32, SW33, SW34, SW35, SW36, SW37, SW38, SW39, SW40: SW_Push Vertical 2; SW_Cherry_MX_2.00u_Vertical_Plate

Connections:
+3V3: D1.2 (A), D2.2 (A), D3.2 (A), D4.2 (A), D14.2 (A), D15.2 (A), D16.2 (A), D17.2 (A), J1.1, J10.1
GND: J1.3, J6.2, J7.2, J8.2, J10.3, J16.2
unnamed: D1.1 (K), J5.3
unnamed: D2.1 (K), J5.2
unnamed: D3.1 (K), J15.2
unnamed: D4.1 (K), J15.1
unnamed: D5.2 (A), SW1.2
unnamed: D6.2 (A), SW2.2
unnamed: D7.2 (A), SW3.2
unnamed: D8.2 (A), SW4.2
unnamed: D9.2 (A), SW5.2
unnamed: D10.2 (A), SW6.2
unnamed: D10.1 (K), D11.1 (K), D12.1 (K), D13.1 (K), D28.1 (K), D29.1 (K), D48.1 (K), J2.1
unnamed: D11.2 (A), SW7.2
unnamed: D12.2 (A), SW8.2
unnamed: D13.2 (A), SW9.2
unnamed: D14.1 (K), J4.1
unnamed: D15.1 (K), J4.2
unnamed: D16.1 (K), J4.3
unnamed: D17.1 (K), J5.1
unnamed: D18.2 (A), SW10.2
unnamed: D5.1 (K), D18.1 (K), D19.1 (K), D30.1 (K), D31.1 (K), D32.1 (K), D33.1 (K), D34.1 (K), D35.1 (K), J14.2
unnamed: D19.2 (A), SW11.2
unnamed: D20.2 (A), SW12.2
unnamed: D20.1 (K), D21.1 (K), D22.1 (K), D36.1 (K), D37.1 (K), D38.1 (K), D39.1 (K), D40.1 (K), D42.1 (K), J14.1
unnamed: D21.2 (A), SW13.2
unnamed: D22.2 (A), SW14.2
unnamed: D23.2 (A), SW15.2
unnamed: D6.1 (K), D7.1 (K), D8.1 (K), D9.1 (K), D23.1 (K), D24.1 (K), J2.3
unnamed: D24.2 (A), SW16.2
unnamed: D25.2 (A), SW17.2
unnamed: D25.1 (K), D26.1 (K), D27.1 (K), D41.1 (K), D43.1 (K), D44.1 (K), D45.1 (K), D46.1 (K), D47.1 (K), J2.2
unnamed: D26.2 (A), SW18.2
unnamed: D27.2 (A), SW19.2
unnamed: D28.2 (A), SW20.2
unnamed: D29.2 (A), SW21.2
unnamed: D30.2 (A), SW22.2
unnamed: D31.2 (A), SW23.2
unnamed: D32.2 (A), SW24.2
unnamed: D33.2 (A), SW25.2
unnamed: D34.2 (A), SW26.2
unnamed: D35.2 (A), SW27.2
unnamed: D36.2 (A), SW28.2
unnamed: D37.2 (A), SW29.2
unnamed: D38.2 (A), SW30.2
unnamed: D39.2 (A), SW31.2
unnamed: D40.2 (A), SW32.2
unnamed: D41.2 (A), SW33.2
unnamed: D42.2 (A), SW34.2
unnamed: D43.2 (A), SW35.2
unnamed: D44.2 (A), SW36.2
unnamed: D45.2 (A), SW38.2
unnamed: D46.2 (A), SW37.2
unnamed: D47.2 (A), SW39.2
unnamed: D48.2 (A), SW40.2
unnamed: J1.2, J10.2
unnamed: J3.1, SW19.1, SW20.1, SW24.1, SW31.1
unnamed: J3.2, SW18.1, SW21.1, SW23.1, SW32.1
unnamed: J3.3, SW17.1, SW22.1, SW34.1, SW40.1
unnamed: J9.1, SW11.1, SW12.1, SW16.1, SW39.1
unnamed: J9.2, SW10.1, SW13.1, SW15.1, SW38.1
unnamed: J9.3, SW1.1, SW5.1, SW9.1, SW14.1, SW37.1
unnamed: J11.1, SW3.1, SW8.1, SW27.1, SW28.1, SW36.1
unnamed: J11.2, SW4.1, SW7.1, SW26.1, SW30.1, SW35.1
unnamed: J11.3, SW2.1, SW6.1, SW25.1, SW29.1, SW33.1
unnamed: J8.3, J12.1
unnamed: J7.1, J12.2
unnamed: J7.3, J12.3
unnamed: J13.1, J16.1
unnamed: J6.1, J13.2
unnamed: J6.3, J13.3
unnamed: J8.1, J15.3

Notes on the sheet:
SeqOctaves 2
Drone Mode
SeqOrder Queue
SeqGate pot
SeqOctaves 0
SeqOrder Up
SeqMode OFF
z PCF mux
SeqMode Latch

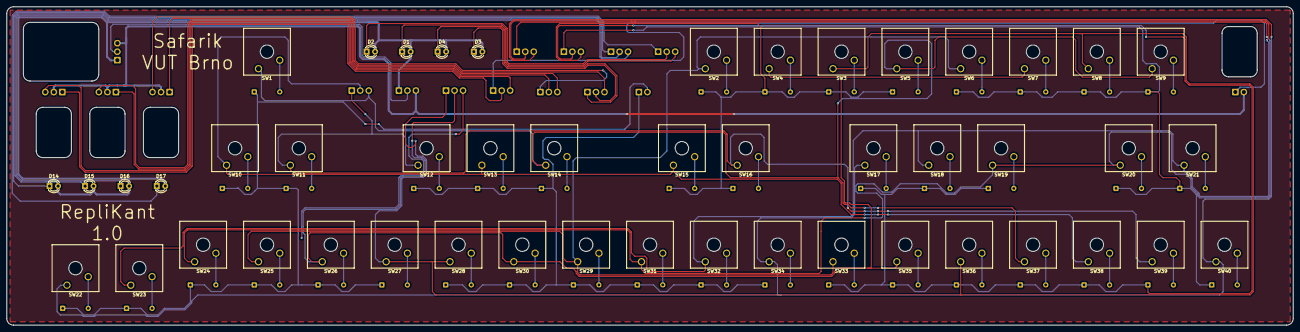
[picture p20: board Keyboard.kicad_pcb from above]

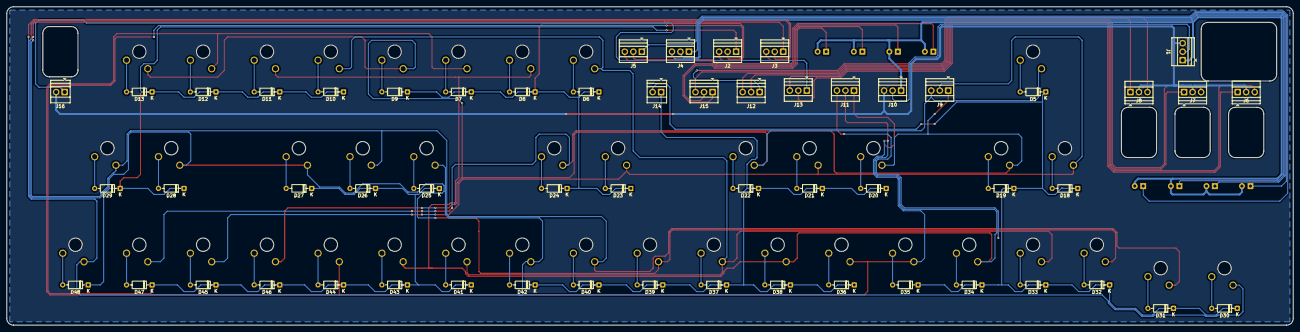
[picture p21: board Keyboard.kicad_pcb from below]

Board: 2 copper layers, 383.9 x 95.0 mm, 104 parts (56 on the bottom side), 72 nets.

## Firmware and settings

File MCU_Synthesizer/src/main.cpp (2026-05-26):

// =======================
// ====== LIBRARIES ======

#include <Arduino.h>

#include "Audio.h"
#include "Wire.h"
#include "SPI.h"
#include "SD.h"
#include "SerialFlash.h"
#include "ILI9341_t3n.h"
#include "ili9341_t3n_OCR_A_Custom_Font.h"

#include "core_pins.h"
#include "imxrt.h"

#include "ResponsiveAnalogRead.h"

// === KEYPAD lib ===
#include "Key.h"
#include "Keypad.h"
// ==================

// ====== end LIBRARIES ======
// ===========================

// ==============================
// ====== Project INCLUDES ======

// === WAVETABLES ===
#include "Wavetables/Saw_Wavetables_AA.h"        // contains saw1  ... saw11
#include "Wavetables/Square_Wavetables_AA.h"     // contains square1 ... square8
#include "Wavetables/Triangle_Wavetables_AA.h"   // contains triangle1  ... triangle8
#include "Wavetables/Sine_Wavetables_AA.h"       // contains sine1 ... sineXY
#include "Wavetables/Instrument_Wavetables_AA.h" // contains instrument1  ... instrumentXY
#include "Wavetables/Voice_Wavetables_AA.h"      // contains voice1 ... voiceXY
#include "Wavetables/LFO_Wavetables.h"           // contains sine, sawRISE, sawFALL, square, noise
// ==================

// === GLOBAL VARIABLES ===
#include "Global_Variables/Global_Variables.h"
#include "Global_Variables/Wavetable_Variables.h"
// ==================

// === SYNTHESIS FUNCTIONS ===
#include "Synthesis/Teensy_Audio.h"
#include "Synthesis/Drone.h"
#include "Synthesis/Filter_Envelope.h"
#include "Synthesis/updateMorphWaveform.h"
#include "Synthesis/LFO.h"
#include "Synthesis/Portamento.h"
#include "Synthesis/KBD_Tracking.h"
// ==================

// === VOICES FUNCTIONS ===
#include "Voices/resetAllVoices.h"
#include "Voices/oscPlayVoice.h"
#include "Voices/oscStopVoice.h"
#include "Voices/updateVoices.h"
// ==================

// === CONFIGURATION ===
#include "Configuration/Pins_Config.h"
#include "Configuration/Setup.h"
#include "Configuration/MIDI_Config.h"
// ==================

// === HARDWARE PERIPHERALS ===
#include "Hardware_Peripherals/Display.h"
#include "Hardware_Peripherals/IO_Expander.h"
#include "Hardware_Peripherals/Encoder_and_Multiplexors.h"
#include "Hardware_Peripherals/LEDs.h"
#include "Hardware_Peripherals/HardwareKeyboard.h"
// ==================

// ====== end Project INCLUDES ======
// ==================================

// ============== Setup ==============
void setup() {
  Serial.begin(115200);
  AudioMemory(64);

  // USB MIDI configuration
  usbMIDI.setHandleControlChange(VirtualControlChange);
  usbMIDI.setHandleNoteOff(myNoteOff);
  usbMIDI.setHandleNoteOn(myNoteOn);

  // all setup functions at once (run once in main loop)
  Synthesizer_setup(); 
} // ================================

// ============== Loop ==============
void loop() {
  // Read the values for virtual MIDI control at the start of the loop
  usbMIDI.read();
    static elapsedMillis lfoUpdateTimer;
    if (lfoUpdateTimer >= LFO_UPDATE_INTERVAL) {
        LFO_update();
        DroneLFO_update();
        lfoUpdateTimer = 0;
    }
  updateEnvelopesPerVoice();
  updateVoices(); 
  
  if ((CurrentSeqMode != 0) && (LFOtypeSelect == 2)) {
    LFO_update();
  }

  // process pending save requests from input
  for (uint8_t s = 0; s < 8; ++s) {
    if (DRONE_requestSave[s]) {
      // copy global variables into snapshot
      DroneSaveValues(s);
      DRONE_requestSave[s] = false;
    }
  }

  DroneSequencer_update();
  checkMux();
  Display_loop();
  Keyboard_update();
  LEDs_update();        // all LED update functions at once - set flags for IOExpander_setLed()
  IOExpander_update();  // flush cached states to IO Expander - batch I2C write
  
}

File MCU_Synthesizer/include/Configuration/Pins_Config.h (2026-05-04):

#ifndef PINS_CONFIG_H
#define PINS_CONFIG_H

// Display pins
#define TFT_DC       9
#define TFT_CS      10
#define TFT_RST    255  // 255 = unused, connect to 3.3V

// === Multiplexer #1 ===
#define MUX_S0          3
#define MUX_S1          4
#define MUX_S2          5
#define MUX_S3          6
#define MUX_1_control   16  // how many mux channels are being used
#define MUX_1_PIN       A15 // common analog input pin for MUX (SIG)
// ===================

// Multiplexer #1 Pins 0-15
#define MUXwave_1       0
#define MUXwave_2       1
#define MUXwave_3       2
#define MUXshape_1      3
#define MUXshape_2      4
#define MUXshape_3      5
#define MUXvolume_1     6
#define MUXvolume_2     7
#define MUXvolume_3     8
#define MUXtune_1       9
#define MUXtune_2       10
#define MUXtune_3       11
#define MUXnoise        12
#define MUXsynthMode    13
#define MUXsubOctave_1  14
#define MUXsubOctave_3  15
// ===================

// === Multiplexer #2 ===
#define MUX_2_control   16   // how many mux channels are being used
#define MUX_2_PIN       A16 // common analog input pin for MUX (SIG)
// ===================

// Multiplexer #2 Pins 0-15
#define MUX_LPF_Cutoff        0
#define MUX_LPF_Res           1
#define MUX_KBD_Track         2
#define MUX_EG_Int            3
#define MUX_HPF_Cutoff        4
#define MUX_Filter_Release    5
#define MUX_Filter_Sustain    6
#define MUX_Filter_Decay      7
#define MUX_Filter_Attack     8
#define MUX_LFO_Delay         9
#define MUX_LFO_Depth         10
#define MUX_LFO_Rate          11
#define MUX_Amplitude_Release 12
#define MUX_Amplitude_Sustain 13
#define MUX_Amplitude_Decay   14
#define MUX_Amplitude_Attack  15
// ===================

// === Multiplexer #3 ===
#define MUX_3_control   13  // how many mux channels are being used
#define MUX_3_PIN       A17 // common analog input pin for MUX (SIG)
// ===================

// Multiplexer #3 Pins 0-15
#define MUX_MasterVolume    0
#define MUXSeqGatePot       1
#define MUX_LFOtype_1       2
#define MUX_LFOtype_3       3
#define MUX_PORTswitch      4
#define MUX_Portamento_Mode 5
#define MUX_Drone_Switch    6
#define MUX_SeqMode_1       7
#define MUX_SeqMode_3       8
#define MUX_SeqOrder_1      9
#define MUX_SeqOrder_3      10
#define MUX_SeqOctaves_1    11
#define MUX_SeqOctaves_3    12
// ===================

// === LED pins ===
#define PIN_LED_Octave_1          22
#define PIN_LED_Octave_2          17
#define PIN_LED_Octave_3          16
#define PIN_LED_Octave_4          15
#define PIN_LED_Sequencer_Rate_1  14
#define PIN_LED_Sequencer_Rate_2  38
// ===================

// === IO Expander pins ===
#define PIN_LED_LFO_Mode_1        3
#define PIN_LED_LFO_Mode_2        2
#define PIN_LED_LFO_Mode_3        4
#define PIN_LED_LFO_Mode_4        5
#define PIN_LED_LFO_Wave_1        8
#define PIN_LED_LFO_Wave_2        9
#define PIN_LED_LFO_Wave_3        10
#define PIN_LED_LFO_Wave_4        11
#define PIN_LED_Sequencer_Rate_3  1
#define PIN_LED_Sequencer_Rate_4  0
#define PIN_LED_LFO_Wave_5        12
#define PIN_LED_Portamento_Rate_1 13
#define PIN_LED_Portamento_Rate_2 14
#define PIN_LED_Portamento_Rate_3 15
#define PIN_LED_Portamento_Rate_4 6
#define PIN_LED_Portamento_Rate_5 7
// ===================

// === Encoder KY-040 pins ===
#define Encoder_SW   0   // push button
#define Encoder_DT   1
#define Encoder_CLK  2
// ===================

// === Hardware Keyboard pins ===
// Matrix - organised in rows and columns
#define Row_1    24
#define Row_2    25
#define Row_3    26
#define Row_4    27
#define Row_5    28
#define Row_6    29
#define Row_7    30
#define Row_8    31
#define Row_9    32
#define Column_1 33
#define Column_2 34  
#define Column_3 35  
#define Column_4 36  
#define Column_5 37  
// ===================

#endif // PINS_CONFIG_H

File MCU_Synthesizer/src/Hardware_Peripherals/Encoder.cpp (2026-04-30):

// === GLOBAL VARIABLES ===
#include "Global_Variables/Global_Variables.h"
// ==================

// === CONFIGURATION ===
#include "Configuration/Pins_Config.h"
// ==================

// === HARDWARE PERIPHERALS ===
#include "Hardware_Peripherals/Display.h"
// ==================

// Encoder state variables
int currentStateCLK;
int lastStateCLK;
unsigned long lastEncButtonPress = 0;

void checkEncoder() {
  currentStateCLK = digitalRead(Encoder_CLK);  // Read the current state of CLK

  // if CLK state has changed
  if (currentStateCLK != lastStateCLK) {
    // decide the direction according to the DT state
    if (digitalRead(Encoder_DT) != currentStateCLK) {
      GlobalBPM++;  // anti-clockwise
    } else {
      GlobalBPM--;  // clockwise
    }

    // BPM value constrain
    GlobalBPM = constrain(GlobalBPM, 40, 240);
    headerDirty = true;
  }

  lastStateCLK = currentStateCLK;

  // Button (not used yet, implement Preset mode later)
  int btnState = digitalRead(Encoder_SW);
  if (btnState == LOW) {
    if (millis() - lastEncButtonPress > 50) {
      //Serial.println("Button pressed!");
    }
    lastEncButtonPress = millis();
  }
  delay(1);
}  

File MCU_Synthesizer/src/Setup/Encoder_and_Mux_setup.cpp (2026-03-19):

#include <Arduino.h>

// === CONFIGURATION ===
#include "Configuration/Pins_Config.h"
#include "Configuration/Setup.h"
// ==================

// === HARDWARE PERIPHERALS ===
#include "Hardware_Peripherals/Encoder_and_Multiplexors.h"
// ==================

void Encoder_and_Mux_setup() {
// === Multiplexor setup (CD74HC4067)
  pinMode(MUX_S0, OUTPUT);
  pinMode(MUX_S1, OUTPUT);
  pinMode(MUX_S2, OUTPUT);
  pinMode(MUX_S3, OUTPUT);

  // === Encoder setup (KY-040)
  pinMode(Encoder_CLK, INPUT);   // Set encoder pins as inputs
  pinMode(Encoder_DT, INPUT);
  pinMode(Encoder_SW, INPUT_PULLUP);
  lastStateCLK = digitalRead(Encoder_CLK);  // Read the initial state of CLK
}

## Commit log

2026-01-14 First commit
    I've been working on this project for the past 7 months as a Bachelor's project at Brno Univesity of Technology. The current state spans the work done in the first semester of third year. Many changes, fixes and new functions will be made, as well as a physical control of parameters using potentiometers and a keyboard matrix for note input.
    [Display.cpp, Encoder.cpp, Global_Variables.cpp]
2026-01-15 Added Keyboard buttons
    Limited keyboard control (7 switches) + 4 LEDs indicating active octave. New bug introduced (when SHIFT button pressed, the pressed notes stay active until pressed again) - might be a feature instead 😏 but fix would be very easy, so I dont care for now.
    [main.cpp]
2026-01-26 Added sequencer
    It still needs some work, and the config is done before compilation now, instead of real-time control by switches and pot. Will be added later, right now Im pushing forward clumsily in order to use my free time as much as possible and I can fix these things later one by one - also, ill be honest, I was using AI quite a lot here, because I was very much clueless. But most quirks have been removed before this commit.
    [main.cpp]
2026-01-27 Bugfixing + Switches
    Improved Drone mode (tune pot is saved now too) and few other things - I spent a whole day fixing bugs, getting rid of some AI slop etc.
    [Global_Variables.cpp, Multiplexors.cpp, Pins_Config.h]
2026-01-29 Sequencer now works in Drone mode
    at least in most cases - this implementation is very difficult, the "Save" Key in Drone requires usually an active voice, which isnt always the case with Step sequencer - between steps, for example. It needed some smart note allocating and automatic muting. Some refinement is still needed later, the bugs are mostly known.
    [main.cpp]
2026-02-04 Controls (MUX changes, I/O Expander)
    Added I/O expander for LEDs, tested toggle switches read by mux, changed some Teensy inout pins - this commit is mostly for testing.
2026-02-04 Controls (MUX changes, I/O Expander) V2
    Correction of the previous commit, which was not pushed in its entirety.
    [Display.cpp, Global_Variables.cpp, IO_Expander.cpp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]
2026-02-05 Fully developed test version
    Correct & breadboard-friendly version for testing, with limited amount of components used, but all the types of components, that will be present in the full version, are represented here. From now on, I will start working on KiCad schematic and next versions should therefore start to finalize the pinouts. Lots of debugging and code splitting (into modules) needs to be done, but Im being pushed by the deadline, therefore I will work on those with the prototype assembled later.
    [Multiplexors.cpp, Pins_Config.h]
2026-03-01 Added remaining muxes, cleaned libs
    Now the code expects three multiplexors in the final inout layout. I also removed a lot of unused files from libraries (examples etc.), which cut the project size to a quarter. I know I dont need to 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
2026-03-03 Comments edit + Antialiasing filter
    Modified modules structure - now the "Include" and "Src" folder makes more sense. Added and translated some comments to English. Lastly, I added antialiasing filter. All of this should work, but I di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
2026-03-08 Added KiCad, Python and MATLAB projects
    also added some first images into readme.
    [Control Panel.kicad_pcb, Control Panel.kicad_sch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]
2026-03-19 Fixed a slash symbol mistake in most includes
    Also updated readme, developed the keyboard code in HardwareKeyboard.cpp, which was previously only made for 9 keys (prototype stage) - now it supports 45. Also added all wavetable names on Display - now the displayed "shape" parameter is probably wrong, I need to correct it by trial and error with compilated project.
    [Display.cpp, Encoder.cpp, Encoder_and_Mux_setup.cpp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]
2026-04-01 Changed STEREO out to symmetrical MONO
    Line out will use symmetrical MONO TRS and Headphone out will just use the LEFT channel, but split it parallel (with 33R resistors).
2026-04-19 First functional prototype version
    The prototype has been put together now, and I had to change the prepared code for hardware keyboard matrix notes mapping so that it corresponds to the real wiring. The same goes for LEDs - right now LED for SeqRate #2 doesnt work, but code should be allright, i need to check the solder joint later. Drone control hasnt been added yet, as well as encoder reading wasnt inverted yet (some pots need the read values to be inverted because of the way they are wired in the project, so i did those changes in Multiplexors.cpp).
    [IO_Expander.cpp, LED_Sequencer_Rate.cpp, Multiplexors.cpp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]
2026-04-30 fixing some functions according to the real implementation P1
    some things, for example potentiometer filtering, encoder readings, and functions like Drone, didnt work the way i wanted with the prototype, so im slowly fixing those. This is part one of those fixes, there will be another tomorrow.
    [Encoder.cpp, Multiplexors.cpp]
2026-05-04 small changes, fixes
    implementing functions to the prototype update part 2
    [Global_Variables.cpp, LED_Sequencer_Rate.cpp, Multiplexors.cpp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]
